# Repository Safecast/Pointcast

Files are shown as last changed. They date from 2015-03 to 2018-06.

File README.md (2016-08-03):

# Pointcast V1.0
New generation nGeigie (work in progress)

Uploads are done through the gateway and go to http://dev.safecast.org

simple software setup:
  - arduino ide 
  - teensyduino or teensy application for uploading hex file into Teensy
  - upgrade firmware instructions are at https://docs.google.com/document/d/16hdhQj_UQkusotejkor8-5BlaK_a2mFPmyVPtsAJ4F8/edit?usp=sharing

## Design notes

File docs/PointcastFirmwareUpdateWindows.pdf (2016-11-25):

2016-11-21 Windows version

Pointcast firmware update (Windows)

1. Download teensy.exe from https://github.com/Safecast/Pointcast/blob/master/app/teensy.zip
2. Extract the file and run the program.
3. Download the Ethernet or 3G zip file as appropriate for your Pointcast device: (https://github.com/Safecast/Pointcast/blob/master/Pointcast_V1_0.V4.2.3_EN.hex.zip and
https://github.com/Safecast/Pointcast/blob/master/Pointcast_V1_0.V4.2.3_3G.hex.zip ).
4. Unzip the Pointcast_V1_0.V4.2.3_EN.hex.zip or the Pointcast_V1_0.V4.2.3_3G.hex.zip to get the HEX file, and place it on your desktop.
5. Run the Teensy.exe
6. Load the hex file from file “open” menu.
7. Switch off the power by:
a. Ethernet Pointcast unplug the ethernet connector.
b. 3G Pointcast disconnect the DC power plug.
8. Remove the clear cover of the Pointcast box by unscrewing the four screws.

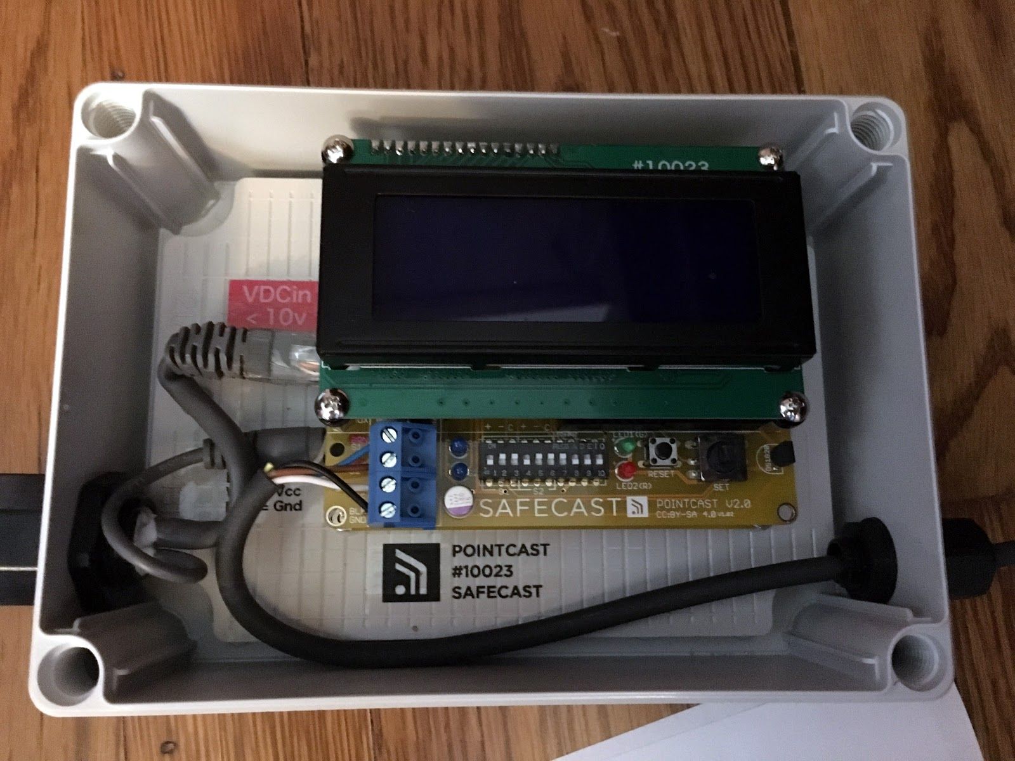
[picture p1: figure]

9. As you can see for the Pointcast V2, there are four layers of boards:
a. The bottom-most gray board with the black Safecast logo and serial number
b. The “Processor Board” that is mounted to it
c. The “Sensor Board” that is plugged into the processor board, and which has the blue screw terminals for the sensor
d. The topmost “Display Board” that is plugged into the Sensor Board.

10. What you want to do is to get access to the Processor Board. Fortunately, you don’t need a screwdriver to do so, because the Sensor Board is merely plugged into a socket on the Processor Board, with nothing more than the tension of the pins and sockets holding it in place.
11. Carefully and gently grab both the left and right sides of the Sensor Board, and wiggle them until the Sensor Board separates from the Processor board, like this:

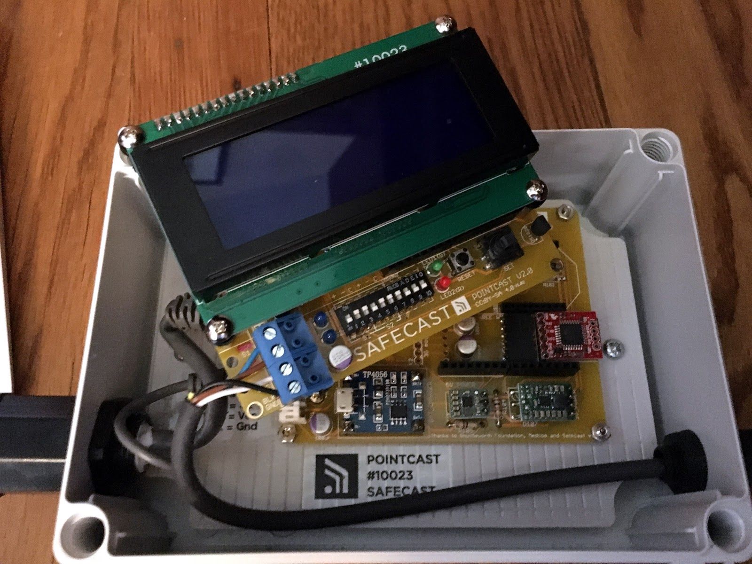
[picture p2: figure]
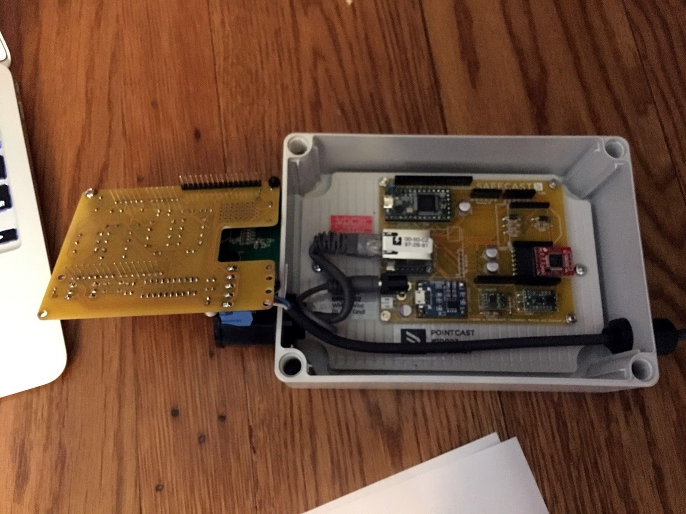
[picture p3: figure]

12. Now, look carefully at the board. You’ll see the Teensy processor card, which has a button on it.

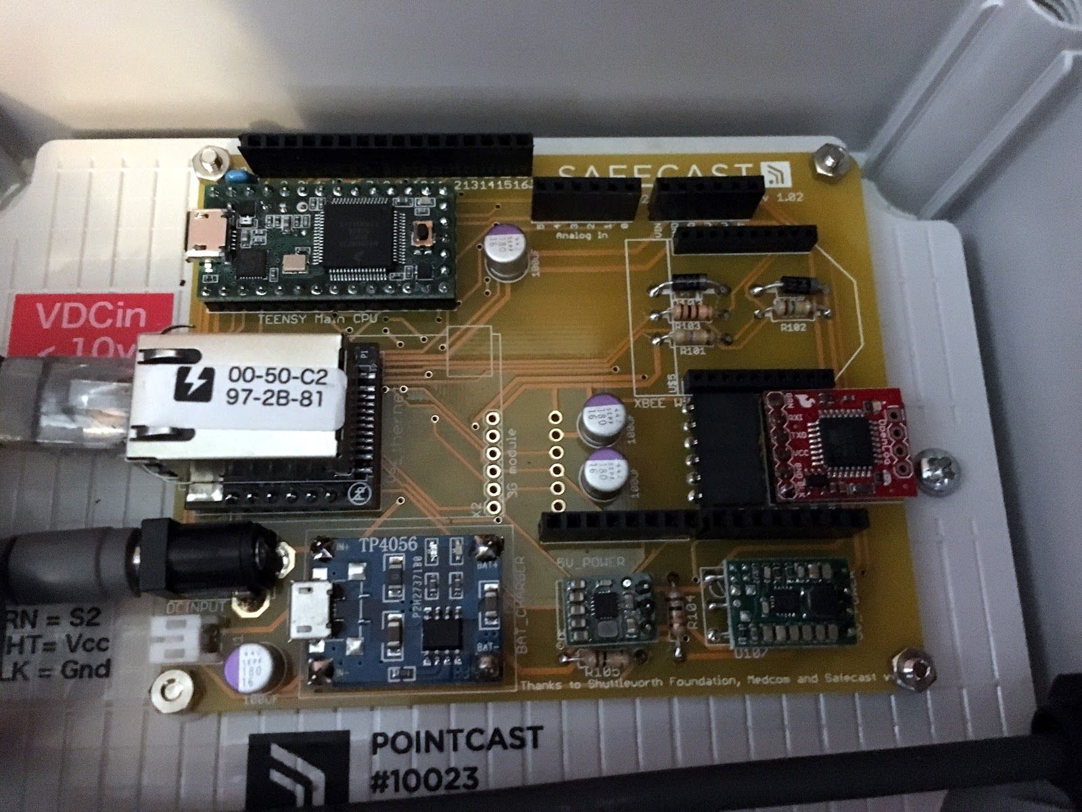
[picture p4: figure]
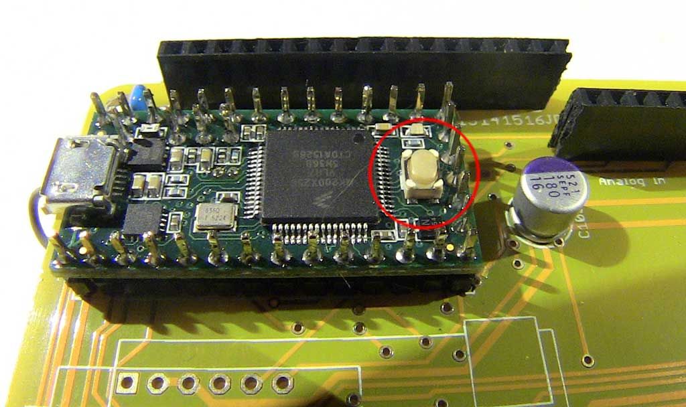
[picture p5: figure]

13. Connect the Teensy on the Processor Board to your computer with the MicroUsb cable.
14. Press the program button of the Teensy.
15. Unplug the Micro USB cable from the Teensy on the Processor Board.
16. Carefully, CAREFULLY plug the Sensor Board back into the Processor Board - looking at an angle at the topmost connector while you’re doing so to ensure that all the pins are aligned and that there aren’t pins sticking outside the socket on one side or another. Gently but firmly make sure the Sensor Board is tightly seated on the Processor Board.
17. Screw the clear plastic cover back onto the Safecast box
18. Plug the ethernet cable back into the box.
19. You’re done. The Pointcast should be booting.

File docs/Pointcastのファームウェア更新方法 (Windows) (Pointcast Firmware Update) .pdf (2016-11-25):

2016-11-21 Windows version

### Pointcastのファームウェア更新方法 （Windows版）

1. Teensy.exe を下記のリンクよりダウンロードします。 https://github.com/Safecast/Pointcast/blob/master/app/teensy.zip
2. ファイルを解凍（展開）し、プログラムを起動させます。
3. Pointcast の機器の仕様に合わせて、Ethernet 又は 3G 用 zip ファイルを下記のリンクよ りダウンロードします。
Pointcast の機器が Ethernet に対応している場合： https://github.com/Safecast/Pointcast/blob/master/Pointcast_V1_0.V4.2.3_EN.hex.zip Pointcast の機器が 3G に対応している場合： https://github.com/Safecast/Pointcast/blob/master/Pointcast_V1_0.V4.2.3_3G.hex.zip
4. 3.の zip ファイルを解凍（展開）して得られた HEX ファイルをデスクトップ上に保存し ます。
5. Teensy.exe を起動します。
6. [File]メニューの[open]より、HEX ファイルを選び、同ファイルを開きます。
7. Pointcast の機器の仕様に合わせて、電源を切ります。
Pointcast の機器が Ethernet に対応している場合：
Pointcast の機器から、Ethernetのプラグを抜きます。
Pointcast の機器が 3G に対応している場合：
Pointcast の機器のDC電源のプラグを抜きます。
8. Pointcast の筐体に付けられている4本のねじを外し、透明色の蓋部を取り外します。


9. Pointcast の機器が、4枚の基板により構成されていることを確認します。

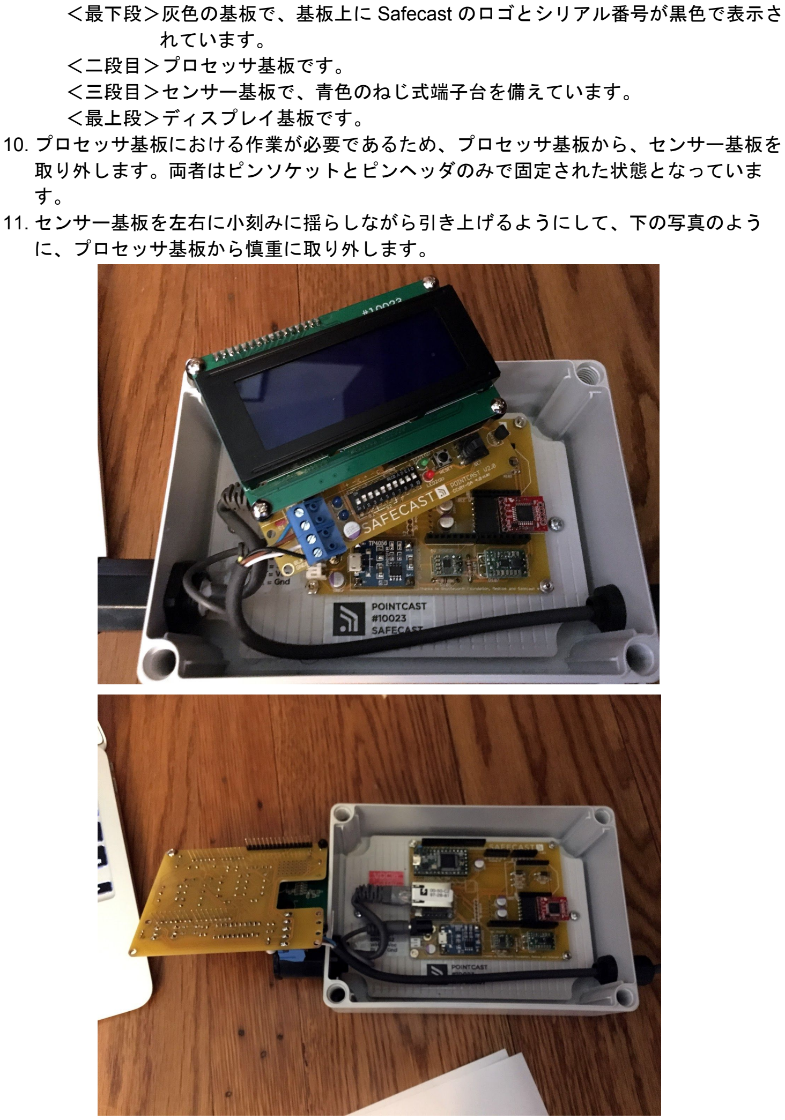
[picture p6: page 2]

＜最下段＞灰色の基板で、基板上に Safecast のロゴとシリアル番号が黒色で表示さ れています。
＜二段目＞プロセッサ基板です。
＜三段目＞センサー基板で、青色のねじ式端子台を備えています。 ＜最上段＞ディスプレイ基板です。
10. プロセッサ基板における作業が必要であるため、プロセッサ基板から、センサー基板を 取り外します。両者はピンソケットとピンヘッダのみで固定された状態となっていま す。
11. センサー基板を左右に小刻みに揺らしながら引き上げるようにして、下の写真のよう に、プロセッサ基板から慎重に取り外します。

12. プロセッサ基板を確認します。プログラムボタン（下の写真の赤色枠中）の付いた Teensy プロセッサ基板が見えます。


13. プロセッサ基板上の Teensy プロセッサ基板とパソコンをマイクロUSBケーブルで接続 します。
14. Teensy プロセッサ基板のプログラムボタンを押します。
15. マイクロUSBケーブルを Teensy プロセッサ基板から外します。
16. センサー基板をプロセッサ基板の上に戻します。＜注意＞全てのピンヘッダがピンソ ケットに収まっていることを確認しながら、慎重に作業を行って下さい。 優しく取り扱 いながらも、センサー基板がプロセッサ基板に固着していることを確認して下さい。
17. Pointcast 筐体の蓋部をねじで取り付けます。Pointcast の機器が 3G に対応している場 合は、これで作業終了となります。
18. Pointcast の機器が Ethernet に対応している場合、 Ethernet ケーブルのプラグを差し込 みます。
19. Pointcast が起動していることを確認して下さい。

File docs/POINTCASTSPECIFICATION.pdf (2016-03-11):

SAFECAST POINTCAST V1.0

Revision:

1.0 April 2015
first draft

1.0.1
incorporated feedback on 1.0 draft

1.0.2
include additional stats under STATS window (1.15)
include parameter for setting the integration window (3.10) (1.6)
add parameter for setting the upload window (e.g. integration window and upload window don’t need to be the same) (3.10) (1.6)
add counter for number of resets, uptime (1.15)
add deadtime correction (3.9)

1.0.3
small changes to 1.1 layout
1.2 screen layout and logic for BAT/EXT power mode detection

1.0.4
move SDCARD screen before TIME screen
NGEIGIE.TXT renamed to PNTCAST.TXT
all screens to 5s
changed SD log format

1.0.5
joystick down on startup, 1 second screen display till “API” screen.
joystick enter(push center button) clears eeprom on startup and clear alarm button on main screen.

1.0.6
Time setup automatically for GMT (later need to be modified for timezones)
SDcard added option for 5 seconds upload for testing/trouble shooting (trb=1)

1.0.7
Handling of MAC
1.08
FAILS handling

1.1 Functions Shield
triple input dual geiger tube input (S1,S2) + one aux input (AUX) float/pull up/pull down 47k for each input line
bypass coupling caps for each input line
LED monitoring of 2 geiger input lines (analog circuit)
Green LED heartbeat
Red LED alarm / error condition
Reset button
Joy stick for screen operation
Digital Temperature sensor
Alarm Buzzer
20x4 LCD interface (dimmable)

1.2 Functions Mother Board
Main controller Teensy
Data Logger (SD card)
System Setup (SD Card)
Power supply USB, External, Battery (3.3 / 5v) Battery charge status (analog input)
Ethernet Interface (optional)
3G Interface (optional)
Xbee Interface for BLE or Wifi (optional)
1.3. SD Card files
PNTCAST.TXT system setup
SENSORS.TXT sensors setup
NETWORK.TXT communication setup
CONFIG.TXT data logger setup (fixed)
XXXXXXXX.LOG historical logs (one file per day)
BUFFER.TXT measurements not uploaded successfully

### 2. SCREEN FLOW

1.1 Startup Screen (5s)

Procedures:
RED/GREEN LED ON (test)
Buzzer ON
Read Device ID from flash memory this is the fixed serial number for the POINTCAST (this can be set from SD card)
INTERUPT: Joy stick enter CLEAR EEPROM settings
INTERUPT: Joy stick DOWN (close screen within 5s timer and other setup screens 1 second display only)

+----+----+----+----+
|SAFECAST POINTCASTv1
|Firmware: X.XX.XX
|DeviceID: XXXX
|http://safecast.org
+----+----+----+----+

1.2 System Status (5s)

Procedures:
read PWR status:
BAT <4.5v
EXT >4.5v
Main power voltage Y.YYV
Bat% (if in BAT mode) based on Nano algo
Pointcast Internal Power Z.ZV
read Tmp sensor (now setup to be send as deviceID+8)

+----+----+----+----+
|SYSTEM
|PWR: EXT/BAT Y.YYV
|Bat: XXX% TNSY: Z.ZV
|Tmp: +XX.XC
+----+----+----+----+

1.3 Read SD Card files (5s)

Procedures:
Read PNTCAST.TXT and set flash memory

Read NETWORK.TXT and set flash memoryRead SENSORS.TXT and set flash memory
If no SD card, then load defaults or use past values set.

⇒ Possible to read name of SDcard and bytes left?
⇒ Show Fail reason?

+----+----+----+----+
|SDCARD FAIL/PASS XXXMB
|PNTCAST: FAIL/PASS
|SENSORS: FAIL/PASS
|NETWORK: FAIL/PASS
+----+----+----+----+

1.4 Time (5s)

Procedures:
Read time from RTC
Read time zone from flash memory (Can be set by PNTCAST.TXT) Adjust time by time zone (setup for UTC)
INTERUPT: Joy stick PUSH (to enter Time Setup screen)
INTERUPT: Joy stick DOWN (close screen within 5s timer)

+----+----+----+----+
|TIME (GMT)
|Date: YYYY/MM/DD
|Time: HH:MM:SS
|Zone: +9
+----+----+----+----+

1.5 Set Time (5s)
does n
This screen should be after network test has been done, so there’s confirmation there’s a network. In case of no network, RTC will be used, with option to use joystick to adjust the RTC. If network is available, attempt will be made to use pool.ntp.org for setting the time. If NTP fails, use RTC, with option to change it (so wait additional 5 seconds for setup)

Time should be set in GMT. Display to show local time.

If RTC is not set manually or by NTP, timestamp to be flagged “invalid”. Some thinking needed how to use RTC when on battery. So check what RTC is when cold boot happens if detected it’s “not set”, flag as invalid, till RTC or manually set has been performed.

Procedures:
Read time from RTC
Read time zone from flash memory (Can be set by PNTCAST.TXT) Adjust time by time zone
INTERUPT: Joy stick:
Up/Down increase/decrease field
Left/Right move prev/next field
Center Set and Close screen

Display on screen if NTP server connected or not

+----+----+----+----+
|RTC check...
|please wait a couple
|seconds...
+----+----+----+----+

succeed:
+----+----+----+----+
|NTP server:
|45.79.78.173
|time:
+----+----+----+----+

fail
+----+----+----+----+
+----+----+----+----+

1.6 POINTCAST parameters (5s)

Procedures:
read parameters from flash
INTERUPT: Joy stick DOWN (close screen within 5s timer)

+----+----+----+----+
|POINTCAST SETUP
|DeviceID: XXXX
|TimeZone: -9
|ALARM-S1: 150 CPM
+----+----+----+----+

+----+----+----+----+
|UPLOAD MODE
|Adaptive: OFF
|Integr Win: 300sec
|Upload Win: 300sec
+----+----+----+----+

1.7 GPS location (5s)

Procedures:
read parameters from flash
INTERUPT: Joy stick DOWN (close screen within 5s timer)

⇒ Option offer function to edit location or read from GPS module

+----+----+----+----+
|GPS LOCATION
|Lon: 12.3456
|Lan: 12.3456
|Alt: 100m
+----+----+----+----+

1.8 SENSORS parameters (3s)

Procedures:
read parameters from flash
INTERRUPT: Joy stick DOWN (close screen within 5s timer) Leave Aux for now, just show NC
INTERUPT: Joy stick DOWN (close screen within 5s timer)

+----+----+----+----+
|SENSORS SINGLE/DUAL
|S1=334 CPM/uSv Cs137

|S2=120 CPM/uSv Cs137
|AUX=NC
+----+----+----+----+

1.9 SENSORS test/auto detect sensors (max 60 sec)

Procedures:
read pulse from S1 if no pulse in 30sec, then FAIL. PASS on first pulse read pulse from S2 if no pulse in 30sec, then FAIL. PASS on first pulse
based on result, update sensor config
INTERRUPT: Joy stick DOWN (close screen within 5s timer)

⇒ Theoretically time out can be set based on the CPM for each sensor bit academic

+----+----+----+----+
|SENSOR TEST
|S1=PASS/FAIL
|S2=PASS/FAIL
|AUX=NC
+----+----+----+----+

1.9 API parameters (5s)

Procedures:
read parameters from flash
INTERRUPT: Joy stick DOWN (close screen within 5s timer) Leave Aux for now
Display full API key (20 chars, no need for “API-KEY” label)

+----+----+----+----+
|API
|S1-ID=XXXX
|S2-ID=YYYY
|sdffkDSFsdkj
+----+----+----+----+

1.10 NETWORK configuration (5s)

Procedures:
read parameters from flash (read which network interface is selected) read NIC/IP/GW from Ethernet or Wifi
read other stuff from 3G like signal strength, carrier, phone number, etc

read NIC from BLE
INTERRUPT: Joy stick DOWN (close screen within 5s timer)
Show top line first, before starting network status check. If time out, show: No LAN detected and wait for 5s

+----+----+----+----+
|NETWORK ETHER (DHCP)
|IP: AAA.BBB.CCC.DDD
|GW: AAA.BBB.CCC.DDD
|ID NN:NN:NN:NN:NN:NN
+----+----+----+----+

+----+----+----+----+
|NETWORK WIFI (DHCP)
|IP: AAA.BBB.CCC.DDD
|GW: AAA.BBB.CCC.DDD
|ID NN:NN:NN:NN:NN:NN
+----+----+----+----+

+----+----+----+----+
|NETWORK 3G
|Signal: |ooooo|
|Carrier: NTT Docomo
|GW: AAA.BBB.CCC.DDD
+----+----+----+----+

+----+----+----+----+
|NETWORK BLE
+----+----+----+----+

ID MAC-Address
if not available from the interface API, show value read from EEPROM
in SD card, parameter for MAC is “macid” that will be stored in EEPROM upon reading the SDcard.

1.11 NETWORK test (5s)

Procedures:

initialize Network Interface (Ethernet/3G/BLE/WIFI)
connect to api.safecast.org/gateways check if Internet is available and if Safecast GW is reachable.. V3.6.7 checks http://api.safecast.org for redirect to https and returns a
301. If successful flags the connection as valid.
if fail, try twice if not, reset and startup with random GW
RED LED if fail. on next time of PASS RED LED will be reset
INTERRUPT: Joy switch DOWN (close screen within 5s timer)
Joy switch to right will ping the api and will pause the progress. Next screen will happen on joy switch down.

⇒ For Ether, 3G, Wifi, BLE sleep interface after test

+----+----+----+----+
|NETWORK TEST (ETHER/3G/BLE/WIFI) |Device: PASS/FAIL
|GW: AAA.BBB.CCC.DDD
|Ping : PASS/FAIL
+----+----+----+----+

1.12 YYYYMMDD.LOG creation (5s)

Procedures:
Create or append to Log file
Read NETWORK.TXT and set flash memory
Read SENSORS.TXT and set flash memory
If no SD card, then load defaults or use past values set.

⇒ Possible to read name of SDcard and bytes left?
⇒ Show Fail reason? In terminal screen

+----+----+----+----+
|DATA LOGGER
|YYYYMMDD.LOG: NEW/FAIL
|XXXX MB Free
+----+----+----+----+

1.13 Main Loop Screen

Procedures:
RED LED ON IF Upload Fail OR CPM-S1=0 OR CPM-S2=0 OR ALARM = TRUE RED LED ON if S1 >> S2 in uSv/h (or other way around factor 3)
GREEN LED ON if RED LED = FALSE (if possible, shortly blink every 10 sec)

If upload fails, show FAIL(n) where n is number of measurements in buffer
FAILS show how many retries left in 3G
FAILS on Ethernet show which sensor send data is failing STS show remaining seconds to next upload and Antenna Strength. In case on Battery, show battery left%. Refresh every 10 seconds.
STS use for any additional detail in case of a RED LED (e.g. “ALPHA/BETA!”, “SPIKE!”, “S1 FAIL”, “BAT LOW”)
LOG show time in local time zone (no summer time adjust!)
INTERRUPT Joystick UP button scroll through all Setup pages
INTERRUPT Joystick DOWN button scroll through Stat pages
INTERRUPT Joystick LEFT button show terminal screen 1.14
INTERRUPT Joystick RIGHT button show Antenna Strength screen (refresh every 1s for quick response)
INTERRUPT RESET button hard reset system

+----+----+----+----+
|S1=9999 CPM m.mm uSh
|S2=10.1kCPM mmmm uSh
|API: HH:MM PASS/FAIL(nnn) |STS: OK 4:50 |ooooo|
+----+----+----+----+

For the first sample, show following status (and show measurements as 0)

|API: HH:MM Startup..

1.14 Terminal screen

+----+----+----+----+
|TERMINAL
|res=z1
|res2=
+----+----+----+----+

Simple screen to live show the output to LPR for in the field trouble shooting. (kind of verbose mode)

1.15 Stat screens

Procedures:
Scroll through automatically, each screen 10s, then return to 1.13 INTERRUPT Joystick DOWN button stat 2
INTERRUPT Joystick UP button goto return to 1.13
Stat-1

+----+----+----+----+
|STATS
|S1peak=9999 CPM
|S2peak=9999 CPM
|Dose=9999999 uSv
+----+----+----+----+

Stat-2:
Procedures:
INTERRUPT Joystick UP button goto Stat-1 page INTERRUPT Joystick Down button return to 1.13

+----+----+----+----+
|up=xxx days hh hour
|#logs=nnnn
|#fail=ffff
|#reset=rrrr
+----+----+----+----+

### 3. DESIGN NOTES

3.1 Adaptive Logging
when radiation levels change by x %, log radiation every y seconds instead of t seconds

3.2 Periodic reset DONE
based on rst parameter, hard reset Pointcast every x
resets every saturday

3.3 Battery low power mode
shutdown display and network subsystems log to BUFFER.TXT file instead

3.4 SD CARD management DONE
create new file for each day YYYYDDMM.TXT
how to handle full SD card TBD ⇒ Reality is to fill 4GB card it will take 10’s of years.

3.5 Log buffer (buffer.txt)
when upload fails, append failed measurements to BUFFER.TXT, increase BUF counter retry if succeeds, upload all from BUF. Set BUF counter to zero when complete. If fails, continue with next measurement

3.6 Dev mode (network.txt) DONE
dev parameter flips between dev and prod servers (retaining all other parameters for seamless promotion of a sensor after test to deployment.

3.7 Set RTC from NTP server (option) DONE

3.8 Wifi
build around Wifi bee module setting of network to be done over Wifi and no need for parameters to setup the module at this point

3.9 Deadtime correction
apply deadtime correction to CPM values before upload
formula:
c_p_m = (unsigned long)((float)c_p_m/(1-(((float)c_p_m*1.8833e-6))));

3.10 Integration and Upload window
integration window (in seconds)
upload window (in seconds)
capability to set the integration window based on the sensor sensitivity
capability to upload data on the same or slower pace as the integration window
these mode may be overwritten by the adaptive upload method, where updates are based on change rather than interval (3.1)

### 4. GATEWAY/API

See:

https://docs.google.com/document/d/1ZxJI0ODhpgQ0rvSRrRyq1NAwyiliyxd7bJkL8JX76e8/edit (https://docs.google.com/document/d/1ZxJI0ODhpgQ0rvSRrRyq1NAwyiliyxd7bJkL8JX76e8/edit)

### 5. SD CARD FILE FORMATS

5.1 PNTCAST.TXT

devid=XXXX | #unique Pointcast DeviceID
lat=34.482597 | #latitude
lon=136.163349 #longitude
alt=100 | #altitude in meters
tws=300 | #integration window in seconds
ups=300 | #upload window in seconds tws <= ups
autow=1 | #auto adaptive window for sudden changes
rst=0 | #periodic reset in days (0 is OFF)
alm=150 | #alarm for S1 sensor in CPM
tz=+9 | #timezone adjust (0 is GMT)
trb=0 | #switch to 5 seconds update mode for troubleshooting

5.2 NETWORK.TXT

intf=EN/3G/BT/WF #interface selection: EtherNet 3G BlueTooth WiFi macid=xx.xx.xx.xx.xx.xx # MAC-Address for Ethernet cards.
uid1=nnnn | # API ID for upload of data from S1 sensor
uid2=nnnn | # API ID for upload of data from S2 sensor
devt1=nnnn | # API device type sensor 1 LND7317 (129) LND712(130)
devt2=nnnn | # API device type sensor 2 LND7317 (129) LND712(130)
api=AzQLKPwQqkyCTDGZHSdy #20 char api key | # API for Pointcast
gw01=107.161.164.166 | # Gateway 01
gw02=107.161.164.163 | # Gateway 02
ssid=mywifi | # WiFI SSID
apn=DMM | # apn for 3G name
pwd=******** | # pwd for Wifi
gwnn= | # Gateway nn
dev=0 | #flip between prod and dev servers

5.3 SENSORS.TXT

s1e=1 | #Sensor 1 enabled
s1f=334 | #Sensor 1 uSv/h conversion factor
s1i=Cs137 | #Sensor 1 Isotope
s2e=1 | #Sensor 2 enabled
s2f=120 | #Sensor 2 uSv/h conversion factor
s2i=Cs137 | #Sensor 2 Isotope
aux=0 | #Aux input (not in use)

5.4 YYYYMMDD.TXT

$PNTDD,95,2015-04-08T03:22:00Z,,,0,A,3428.9558,N,1369.8009,E,1,A,,*5C $PNTXS, 1001,23,4.89,*4D (device id, temperature, voltage, etc)

5.5 BUFFER.TXT

$PNTDD,95,2015-04-08T03:22:00Z,,,0,A,3428.9558,N,1369.8009,E,1,A,,*5C $PNTXS, 1001,23,4.89,*4D

5.6 CONFIG.TXT

9600,26,3,2

### 6. FLOW DIAGRAM

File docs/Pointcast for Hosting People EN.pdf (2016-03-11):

160227

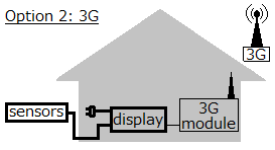
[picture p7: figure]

1

Thank you for your interest in and support of Safecast, and for participating in the Pointcast project.

Pointcast Project and Instrument:

The Pointcast project is intended to visualize changes in radiation levels over time at fixed locations all over the world, by installing real time radiation monitoring systems.

The Pointcast instrument can detect alpha, beta and gamma radiation. It uses a communication module (external dimensions: 120x175x60mm) either indoors or outdoors, and an outdoor dual-sensor module (external dimensions: 80x160x65mm), connected to each other by a cable. The instrument will operate with an AC adapter (5-7.5VDC 2A). The system is connected to the Internet, and the measurement data will be displayed on our webpage. (http://realtime.safecast.org)
Photo
Communication module
Dual Sensors module
The Pointcast instrument will be installed by Safecast volunteers.

Joining and Cooperating with the Pointcast project:

Installing the Pointcast instrument requires you to supply power, and internet access through a LAN cable. If internet access is not available at your location, Safecast can supply a 3G wireless module.

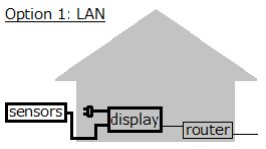
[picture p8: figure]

If any errors occur on the Pointcast instrument, the communication module will alert you with a red LED and beep three times.

What the Pointcast Instrument Shows You：

On the display of the Pointcast communication module, you will be able to see the real time radiation levels detected from both sensors, in CPM and μSv/h. Sensor 1 (displayed as S1) is a pancake-style Geiger-Müeller tube designed to detect alpha, beta and gamma radiation. Sensor 2 (displayed as S2) is

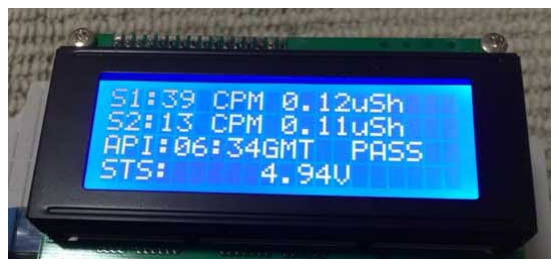
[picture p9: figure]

an end window type Geiger-Müeller tube configured for detecting gamma radiation.

160227

2

Normally, the both sensors will show approximately the same radiation levels (±25%). If the gamma radiation level in the air is high, both will indicate the level of gamma radiation (since both sensors detect gamma radiation). However, if there are nuclides in the air that emit beta or alpha radiation, besides gamma, the pancake style sensor (S1) will likely read higher. In that case, please refer to the CPM reading, not the dose rate (µS/h), because it will not be applicable for S1. Regarding Sensor 2 (S2), readings of both CPM and the dose rate are applicable.

Following “API:,” the last time at which the data was sent to our server is displayed in Greenwich Mean Time (GMT), and “PASS” means that the data was uploaded to our server successfully. For Japan time, please add nine hours.

On the last line of the display, when nothing is displayed after “STS:,” it means that the communication module is working properly. The voltage indication on the right side is the input voltage to the communication module circuit from power supply. It should be between 3.5 and 7.5 V.

On the case of the Pointcast communication module, two URLs are given for locating the real time data from each sensor online.

Precautions after Installing the Pointcast Instrument:

- Keep the Pointcast instrument away from vibration, high humidity, heat, and direct sunlight as much as possible.
- Please do not let the Pointcast instrument directly touch radioactive materials, in order to prevent contamination from distorting the readings.
- Please do not scratch or damage the mica window of the Pointcast sensor module.
- Unless requested to do so by our volunteers, please do not open, uninstall, disassemble, repair, or modify the Pointcast instrument.

If You Find Any Failure of the Pointcast Instrument:

We will request you to provide your contact information to us. A volunteer will probably contact you regarding the condition of the Pointcast instrument. In such a case, a timely response will help resolve the problem quickly. If you have a preferable day and time to be contacted, please let us know.

Our volunteers will ask you to describe the problem. Depending on the problem, we may ask you to assist in fixing the failure. In this case, your help would be appreciated.

Contact Safecast Pointcast Project:
Pieter Franken (Tel: 080-3351-4519 E-mail: pieter@safecast.org) Rob Oudendijk (Tel: 080-2260-5966 E-mail: rob@safecast.org) Kiki Tanaka (Tel: 090-9800-3337 E-mail: kiki@safecast.org)

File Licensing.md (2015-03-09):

Licensing Read Me

Licensing can be confusing. We’ll try to make it a little less so.

Design, hardware, software, design and website content is shared by Safecast under the licenses specified below. 

When you contribute to Safecast by [participating in this event] OR [submitting content of information to the webpage] OR [(Github) submitting a pull request, testing or bug reporting] OR [sending data from your Safecast device] then you license all of your contribution to Safecast and to all the world under these same licenses. Safecast will be attributed as the source.

	•	All Data is Creative Commons Zero (http://creativecommons.org/publicdomain/zero/1.0/), anyone is free to make any use of the data, attribution is not legally required but is encouraged;
	•	All Design is Creative Commons Attribution Share-Alike (http://creativecommons.org/licenses/by-sa/4.0/), anyone is free to copy, edit and republish the design but must make it clear Safecast is the source and the design must be published under the same or a compatible license;
	•	All ufnctional aspects of design are under the Berkeley Software Distribution License (https://blog.safecast.org/bsd) in respect of copyright and the XL1.0 Cross Licence 
	•	(http://blog.safecast.org/wp-content/uploads/2012/05/xl_crosslicense.pdf) in respect of patent;
	•	Web Content is under Creative Commons Attribution Non Commercial (http://creativecommons.org/licenses/by-nc/3.0/), anyone can copy and remix the what is on the website but must attribute Safecast and anyone else specified by  Safecast.

“Safecast” and the safecast logo are Registered Trademarks of the Momoko Ito Foundation, a 501(c)3 Non-profit, you can't use them without permission. For permission email

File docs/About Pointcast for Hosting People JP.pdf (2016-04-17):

セーフキャストの活動にご賛同いただき、Pointcast（ポイントキャスト）プロジェ クトにご参加・ご協力いただき有難うございます。

ポイントキャスト・プロジェクトと機器について:

ポイントキャスト・プロジェクトは、リアルタイム放射線量モニタリング・システ ムを世界各地に設置することにより、一定の場所における経時的な放射線量の変化 を可視化することを目的としています。

ポイントキャスト機器は、通信器（外寸: 120 x 175 x 60 mm）を屋内または屋外に設 置し、デュアルセンサー・モジュール（外寸: 80 x 160 x 65 mm）を屋外に設置し、両 者をケーブルで接続することにより、アルファ、ベータ、ガンマ線を検出すること が可能です。同機器は、AC アダプター（5V、2A）で作動します。データはインター ネットを介して当団体ウェブサイトに表示されます。（http://realtime.safecast.org）

通信器：

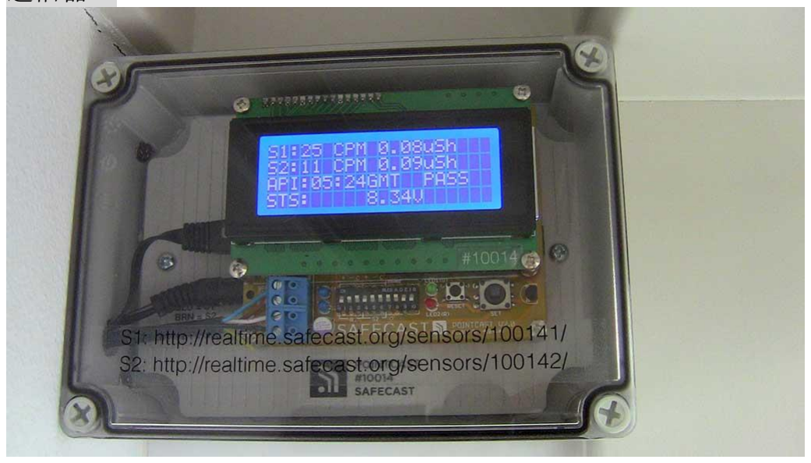
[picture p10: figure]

デュアルセンサー・モジュール：

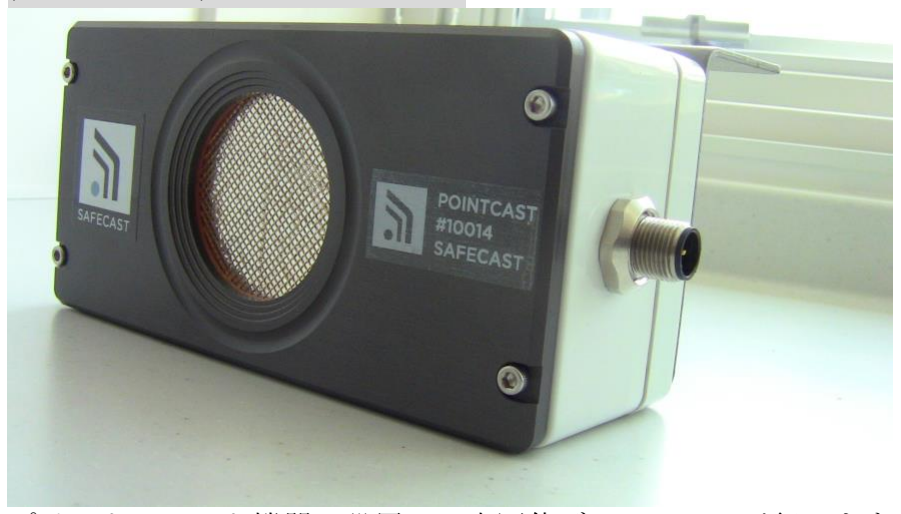
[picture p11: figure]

ポイントキャスト機器の設置は、当団体ボランティアが行います。

ポイントキャスト・プロジェクトへのご参加・ご協力について:

ポイントキャスト機器を設置するに当たり、電源と LAN ケーブルによるインターネ ットへの接続環境をご提供いただきます。ご自宅にインターネット環境がない場合、 当団体が 3G 通信機器をご用意します。

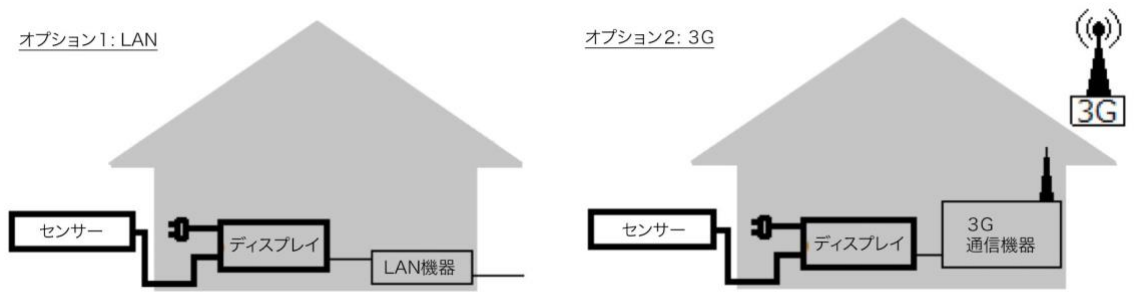
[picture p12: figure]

万が一、機器に不具合が生じた場合、通信モジュール部の赤色 LED 警告灯とビープ 音（3 回）により、異常をお知らせします。

ポイントキャスト機器から判ること:

通信器のディスプレイには、２台のセンサーから検出さ
れた放射線量がリアルタイムで CPM と μSv/h の単位に て表示されます。センサー１（ディスプレイ上では S1） は、パンケーキ型ガイガー＝ミュラー計数管を利用し、
アルファ、ベータ、ガンマ線を検出するように設計され

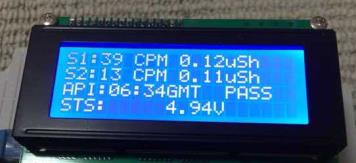
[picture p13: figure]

ています。センサー２（ディスプレイ上では S2）は、端窓型ガイガー＝ミュラー計 数管を利用し、ガンマ線を検出するように設計されています。大抵の場合、両セン サーは、ほとんど同じ放射線量を表します（±25%）。大気中にガンマ線量が高い 場合、両センサーともガンマ線を検出するため、両センサーはガンマ線量の値を示 します。大気中の核種がガンマ線以外にベータ線やアルファ線を放出する場合は、 センサー１の方が高い値を示します。この場合、センサー１に関しては、線量率 (µS/h)の測定値は不適切な値であるため、CPM 値のみをご参考下さい。センサー２に 関しては、線量率(µS/h)値と CPM 値ともにご参考いただけます。

ディスプレイ上の「API:」の項目は、API にデータを送信した最終時刻をグリニッジ 平均時（GMT）で表します。「PASS」の表示は、データがサーバーにアップロード されたことを示します。日本時間への変換は、GMT より 9 時間進めて下さい。

ディスプレイ上の最下行の「STS:」の項目に何も表示がない場合は、通信器が正常に 作動していることを示します。右側に表示される電圧の値は、電源から通信器へ入 力される電圧（通常 3.5〜7.5V）の値を示します。

通信器の上蓋に示す URL は、センサー１（S1） とセンサー２（S2）それぞれのリア ルタイムデータが表示されるウェブサイトのアドレスです。

ポイントキャスト機器を設置後にご注意いただきたい事項:

- 機器が、振動、高温、多湿、直射日光をできる限り避けることができるようご配 慮ください。
- 機器の汚染を避けるため、同機器が放射性物質に触れないようにしてください。
- デュアルセンサー・モジュールの雲母窓を引っかく等、傷をつけないでください。
- 当団体ボランティアから依頼しない限り、機器を開けたり、取り外したり、その 他、解体、修理、改造しないでください。

ポイントキャスト機器に故障や不具合が発生した場合:
ポイントキャスト機器に故障や不具合を発見されましたらプロジェクト窓口に至急 ご連絡ください。当団体ボランティアが同機器の状態についてお尋ねします。機器 の状態により対処方法は異なりますが、ご協力をお願いする場合があります。その 際は、ご対応をいただきたく、よろしくお願い致します。

また、当団体ボランティアからも、機器の状態に関して、ご連絡をすることがある ため、同プロジェクトにご参加いただく皆様には、連絡先情報を当団体にご登録い ただいております。当団体からのご連絡には、必ずご応答いただきたく、よろしく お願い致します。当団体からご連絡をする場合にご希望の時間帯・曜日等ございま したら、予めお知らせください。

セーフキャスト・ポイントキャスト・プロジェクト窓口: ピーテル・フランケン（Tel: 080-3351-4519 E-mail: pieter@safecast.org） ロブ・アウデンダイク（Tel: 080-2260-5966 E-mail: rob@safecast.org） 田中 響子（Tel: 090-9800-3337 E-mail: kiki@safecast.org）

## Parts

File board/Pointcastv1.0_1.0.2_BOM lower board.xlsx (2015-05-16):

Part | Value | Device | Package | Description | PROD_ID
3V_POWER |  | POLOLU_D24V3AXV | POLOLU_D24VXAYV_HC | Pololu Adjustable Step Down Voltage Regulators Series D24V3A_V (300 mA)0.4x0.6""
5V_POWER |  | POLOLU_S7V8F5 | POLOLU_S7V8F5 | POLOLU_S7V8F5
BAT_CHARGER | TP4056_CHARGER | TP4056_CHARGER | TP4056 | TP4056
C2 | 0.1uF | C-EU025-024X044 | C025-024X044 | CAPACITOR, European symbol
C101 | 100uF | CAP_POLPTH1 | CPOL-RADIAL-100UF-25V | Capacitor Polarized
C102 | 100uF | CAP_POLPTH1 | CPOL-RADIAL-100UF-25V | Capacitor Polarized
C103 | 100uF | CAP_POLPTH1 | CPOL-RADIAL-100UF-25V | Capacitor Polarized
C104 | 100uF | CAP_POLPTH1 | CPOL-RADIAL-100UF-25V | Capacitor Polarized
CN1 |  | JST_2PIN-THM-RA | JST-PH-2-THM-RA | JST 2-Pin Connectors of various flavors
D101 | 1N4004 | 1N4004 | DO41-10 | DIODE
D103 | 1N4004 | 1N4004 | DO41-10 | DIODE
D105 | 1N4004 | 1N4004 | DO41-10 | DIODE
D107 | 1N4004 | 1N4004 | DO41-10 | DIODE
D108 | 1N4004 | 1N4004 | DO41-10 | DIODE
DATALOGGER | OPENLOG | OPENLOG | OPENLOG | Openlog
DCINPUT | 5Volt | DC21MMX | DC-21MM
FRAME1 | FRAME-LEDGER | FRAME-LEDGER | CREATIVE_COMMONS | Schematic Frame
JP3 |  | M16PTH | 1X16 | 1x16 .1 header"
R101 | 470k | R-US_0207/10 | 0207/10 | RESISTOR, American symbol
R102 | 150k | R-US_0207/10 | 0207/10 | RESISTOR, American symbol
R103 | 100 | R-US_0207/10 | 0207/10 | RESISTOR, American symbol
R104 | 10K | R-US_0207/10 | 0207/10 | RESISTOR, American symbol
R105 | 100k | R-US_0207/10 | 0207/10 | RESISTOR, American symbol
TEENSY | TEENSY Main CPU | TEENSY_3.0_ALLPINS | TEENSY_3.0_ALLPINS | Teensy 3.0 with all pin holes and optional SMD-mount unshrouded header on bottom of Teensy 3.0. For more basic versions, see 'Basic', '+4' and 'AllAnalogPins'.Requires the installation of a un-shrouded SMD header on the underside of the Teensy 3.0
U$5 | XBEE WiFi/BLE | XBEE-2B2 | XBEE-SILK | Xbee module footprints
U6 | Ethernet | WIZ820IO_DEVICE'DUAL-IN-LINE' | WIZ820IO | WIZnet, WIZ820io plug in module incl. W5200 chip and MagJack
X2 | 3G module | M06SILK_FEMALE_PTH | 1X06 | Header 6 | CONN-08437
X4 | 3GS shield | ARDUINO_SHIELDLABEL | DUEMILANOVE_SHIELD | Arduino shield footprint

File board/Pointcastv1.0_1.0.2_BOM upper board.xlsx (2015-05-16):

Part | Value | Device | Package | Description | MF | OC_ADAFRUIT | OC_MOUSER | OC_NEWARK
C1 | 0.1uF | C-EU025-024X044 | C025-024X044 | CAPACITOR, European symbol
C2 | 0.1uF | C-EU025-024X044 | C025-024X044 | CAPACITOR, European symbol
C3 | 0.1uF | C-EU025-024X044 | C025-024X044 | CAPACITOR, European symbol
C4 | 100uf | CAP_POLPTH1 | CPOL-RADIAL-100UF-25V | Capacitor Polarized
C5 | 0.1uF | C-EU025-024X044 | C025-024X044 | CAPACITOR, European symbol
D1 |  | DIODEDIODE_BIG | DO41-10 | Diode
D2 |  | DIODEDIODE_BIG | DO41-10 | Diode
FRAME1 | FRAME-LEDGER | FRAME-LEDGER | CREATIVE_COMMONS | Schematic Frame
J1 | OSTTH050160 | OSTTH050160 | EDSTL130-05 | 5mm Terminal Header
JP3 | Extended header | M16PTH | 1X16 | 1x16 .1 header"
LED1 | (G) | LED3MM | LED3MM | LED
LED2 | (R) | LED3MM | LED3MM | LED
PAD1 | AUX | 2,15/1,0 | 2,15/1,0 | THROUGH-HOLE PAD
PAD2 | 5V | 2,15/1,0 | 2,15/1,0 | THROUGH-HOLE PAD
PAD3 | GND | 2,15/1,0 | 2,15/1,0 | THROUGH-HOLE PAD
PAD4 | 3.3V | 2,15/1,0 | 2,15/1,0 | THROUGH-HOLE PAD
R1 | 47k | R-US_0207/10 | 0207/10 | RESISTOR, American symbol
R2 | 47k | R-US_0207/10 | 0207/10 | RESISTOR, American symbol
R3 | 470 | R-US_0207/10 | 0207/10 | RESISTOR, American symbol
R4 | 470 | R-US_0207/10 | 0207/10 | RESISTOR, American symbol
R5 | 10k | R-US_0207/10 | 0207/10 | RESISTOR, American symbol
R6 | 10k | R-US_0207/10 | 0207/10 | RESISTOR, American symbol
R7 | 4.7k | R-US_0207/10 | 0207/10 | RESISTOR, American symbol
R8 | 1k | R-US_0207/10 | 0207/10 | RESISTOR, American symbol
R9 | 100k | R-US_0207/10 | 0207/10 | RESISTOR, American symbol
R11 | 1k | R-US_0207/10 | 0207/10 | RESISTOR, American symbol
R12 | 100 | R-US_0207/10 | 0207/10 | RESISTOR, American symbol
R13 | 47k | R-US_0207/10 | 0207/10 | RESISTOR, American symbol
R14 | 47k | R-US_0207/10 | 0207/10 | RESISTOR, American symbol
R15 | 10k | R-US_0207/10 | 0207/10 | RESISTOR, American symbol
R16 | 4.7k | R-US_0207/10 | 0207/10 | RESISTOR, American symbol
R17 | 4.7k | R-US_0207/10 | 0207/10 | RESISTOR, American symbol
R18 | 100k | R-US_0207/10 | 0207/10 | RESISTOR, American symbol
R19 | 100 | R-US_0207/10 | 0207/10 | RESISTOR, American symbol
RESET | RESET | DTS-6 | DTS-6
S1 |  | LED3MM | LED3MM | LED
S2 |  | LED3MM | LED3MM | LED
SET |  | SKQUCAA010 | SKQU | Multi Control Devices TACT Switch - 4-directional with Center Push Type. | ALPS | 504 | 688-SKQUCA | 59M1983
SG1 | BUZZER | BUZZERPTH | BUZZER-12MM | Buzzer 12mm
SW1 |  | SW_DIP-10 | EDG-10 | DIP SWITCH
T1 | 2SC1815 | 2SC1815 | TO92-ECB | NPN EPITAXIAL TRANSISTOR
T2 | 2SC1815 | 2SC1815 | TO92-ECB | NPN EPITAXIAL TRANSISTOR
TEMP | AVA_DS1820TO92 | AVA_DS1820TO92 | AVA_DS1820 | DS18B20
X1 | LCD-HD447804-HOLES20X4-4HOLES | LCD-HD447804-HOLES20X4-4HOLES | LCD-20X4-4HOLES
X3 | 3GS shield | ARDUINO_SHIELDLABEL | DUEMILANOVE_SHIELD | Arduino shield footprint

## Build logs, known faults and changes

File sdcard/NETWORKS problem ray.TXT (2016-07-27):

uid1=100231
uid2=100232
devt1=129
devt2=130
intf=EN
macid=90:A2:DA:0E:E0:5E
gw2=107.161.164.166
gw1=107.161.164.163
ssid=mywifi
pwd=12345678
gwn=test
dev=1
apn=SORA

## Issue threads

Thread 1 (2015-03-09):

Software requests/ideas/bug etc..

robouden, 2015-03-09:

robouden, 2015-03-09:
To be implemented :
- Multiple gateway list randomly selected.  Read from SDcard.
- Setup on SDcard for switching Ethernet or 3G.
- Display messages and layout of screen.

robouden, 2015-11-16:
Other things to be worked on:
- timezones setup
- eprom clear from menu
- dead compensation
- failures on SDcard and falling codes
- alarm set
- switch Ethernet-3G on SDcard

Closed 2016-07-08.

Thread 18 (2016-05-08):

9 volt test

robouden, 2016-05-08:
Test for 9 volt adaptor

robouden, 2016-05-08:
Reset for 9 Volt adaptor does not seem to work

robouden, 2016-05-15:
Reset tested works  on Ethernet and does work correctly.

Closed 2016-05-15.

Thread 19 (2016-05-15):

Xbee tests

robouden, 2016-05-15:

nokton, 2016-05-15:
Rob, please see if the pins that the XBee uses are wired on the motherboard correctly or not before testing

 Pieter

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

robouden, 2016-05-15:
will do

robouden, 2016-05-15:
Xbee connected to pin 24/25 on teensy. Software serial test for sending same data from serial 0 (Openlog) to serial 2 (Xbee). Works now

Closed 2016-05-15.

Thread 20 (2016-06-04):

hardware reset

robouden, 2016-06-04:
Hardware pin reset connected to button and i/o pin. So hardware reset will be possible from software

Closed 2016-06-26.

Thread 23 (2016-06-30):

Software reset does not reset 3G module or Ethernet board.

robouden, 2016-06-30:

Closed 2016-07-08.

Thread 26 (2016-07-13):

Random time for restarts

robouden, 2016-07-13:
Weekly restarts needs to be random for preventing all the sensors send data at the same time.

nokton, 2016-07-13:
Make it a function of time elapsed till start + a random seed, not based on RTC

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

robouden, 2016-07-13:
Time elapsed till start  or time elapsed from start ?  I was thinking RTC with random seed so we know roughly restarts times. Maybe within and hour.

nokton, 2016-07-13:
From start

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

thinrope, 2016-07-14:
Each boot, write down (flash) millis()+1week, then periodically (hourly?) check the value and compare to current, reboot if needed. If reboot happens in less than one week - fine; otherwise the device will work at most one week (unless it gets stuck); make sure shorter (1h?) watchdog is set.

Closed 2016-07-21.

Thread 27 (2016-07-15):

First measurement to high

robouden, 2016-07-15:
After power up first measurement is to high.

robouden, 2016-07-17:
V3.9.7 fixed issue

Closed 2016-07-17.

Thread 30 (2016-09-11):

realtime website show "misses" in sending data

robouden, 2016-09-11:
A table and graph for displaying missed data of sensor at RT website.

robouden, 2016-09-11:
test is at https://docs.google.com/spreadsheets/d/1M-cGRrwzN5xHKK9vO_FhC3u_J3ECEa8LG8dkTrSwHu4/edit?usp=sharing

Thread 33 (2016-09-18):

replace println() with println("")

robouden, 2016-09-18:

Closed 2016-09-18.

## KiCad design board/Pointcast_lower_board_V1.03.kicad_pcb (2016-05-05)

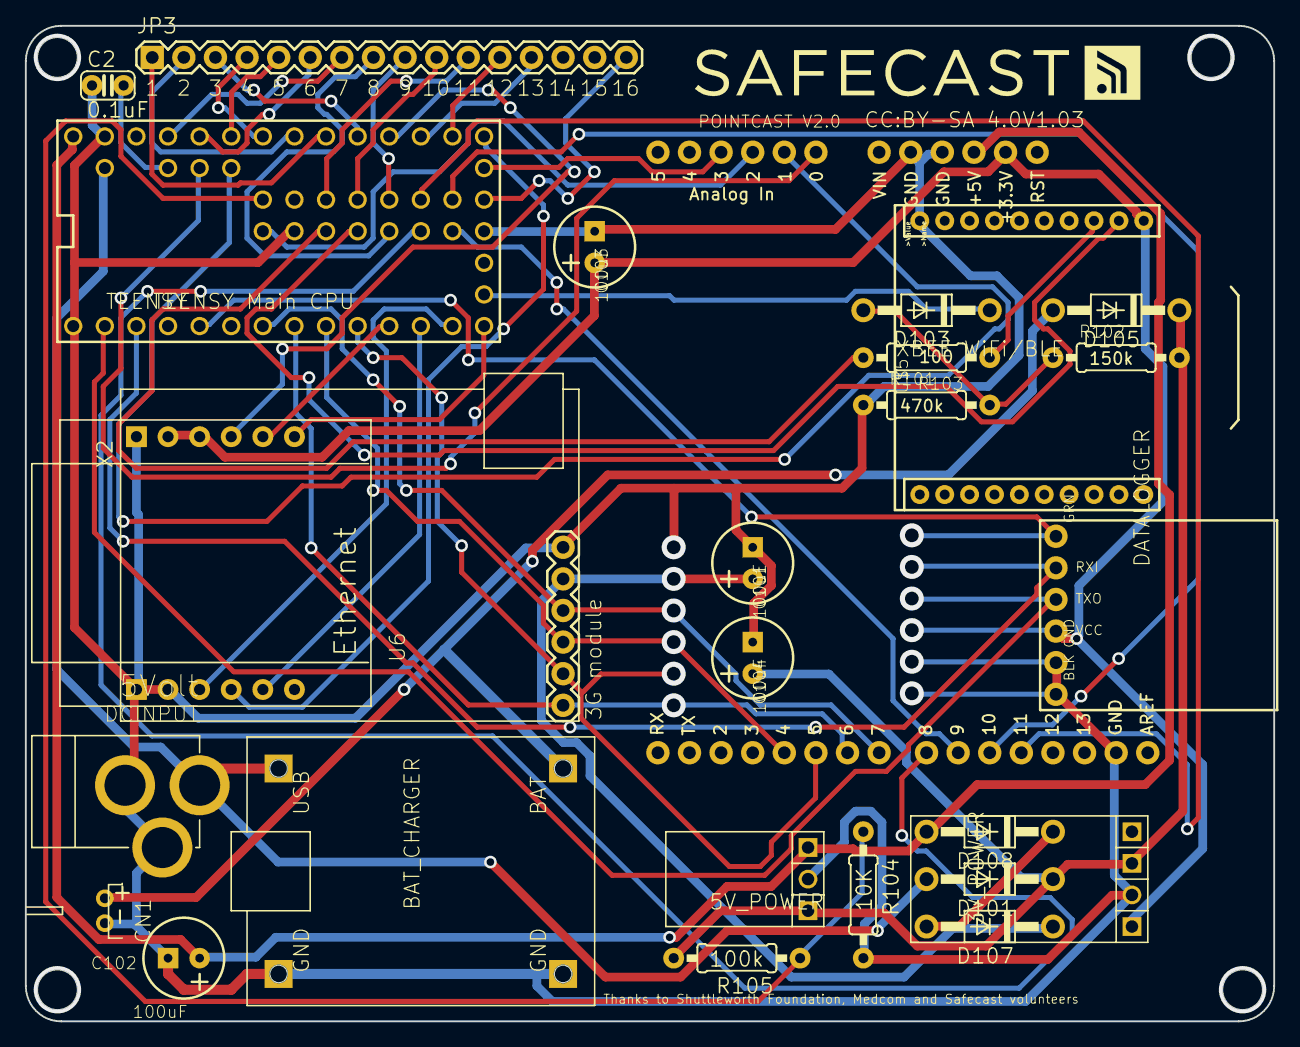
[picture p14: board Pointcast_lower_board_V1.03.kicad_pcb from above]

Board: 2 copper layers, 100.3 x 80.0 mm, 33 parts (0 on the bottom side), 36 nets.

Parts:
3V_POWER: POLOLU_D24VXAYV_HC
5V_POWER: POLOLU_S7V8F5
@HOLE0, @HOLE1, @HOLE2, @HOLE3: (no value)
BAT_CHARGER: TP4056_CHARGER; TP4056
C2: 0.1uF; C025-024X044
C101, C102, C103, C104: 100uF; CPOL-RADIAL-100UF-25V
CN1: JST-PH-2-THM-RA
D101, D103, D105, D107, D108: 1N4004; DO41-10
DATALOGGER: OPENLOG
DCINPUT: 5Volt; DC-21MM
FRAME1: FRAME-LEDGER; CREATIVE_COMMONS
JP3: 1X16
R101: 470k; 0207%2f10
R102: 150k; 0207%2f10
R103: 100; 0207%2f10
R104: 10K; 0207%2f10
R105: 100k; 0207%2f10
TEENSY: TEENSY Main CPU; TEENSY_3.0_ALLPINS
U6: Ethernet; WIZ820IO
U$5: XBEE WiFi/BLE; XBEE-SILK
U$10: SAFECAST_LOGO1
X2: 3G module; 1X06
X4: 3GS shield; DUEMILANOVE_SHIELD

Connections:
A10: TEENSY.A10, X4.A0
A11: TEENSY.A11, X4.A1
A12: TEENSY.A12, X4.A2
BAT: BAT_CHARGER.BAT, CN1.1, D105.A
D5: TEENSY.5, X2.4, X4.D7
D6: TEENSY.6, X2.1, X4.D6
D7: TEENSY.7, X2.3, X4.D4
D8: TEENSY.8, X2.2, X4.D5
D9: TEENSY.9, U6.J2.5
D10: TEENSY.10, U6.J1.5
D11: TEENSY.11, U6.J1.3
D12: TEENSY.12, U6.J2.6
D13: TEENSY.13, U6.J1.4
D26: JP3.8, TEENSY.26
D27: TEENSY.27, X4.D8
D28: TEENSY.28, X4.D9
D29: TEENSY.29, X4.D10
D30: TEENSY.30, X4.D11
D31: JP3.9, TEENSY.31
D32: JP3.10, TEENSY.32
D33: JP3.11, TEENSY.33
GND: 3V_POWER.G, 5V_POWER.G, BAT_CHARGER.GND, BAT_CHARGER.GND2, C2.1, C101.1, C102.1, C103.1, C104.1, CN1.2, DCINPUT.1, DCINPUT.3, R101.1, R104.2, TEENSY.AGND, TEENSY.GND, TEENSY.GND1, TEENSY.GND2, U6.J1.1, U6.J1.2, U6.J2.1, U$5.10, X2.6
unnamed: D103.C, TEENSY.VBAT
unnamed: D103.A, R101.2, R102.1
unnamed: R104.1, R105.1, TEENSY.A13
unnamed: R103.1, U$5.3
unnamed: C2.2, TEENSY.AREF
unnamed: D107.A, D108.C
unnamed: C101.2, D107.C, X2.5
PGM: JP3.16, TEENSY.PGM
PWRIN: 3V_POWER.I, 5V_POWER.I, C104.2, D101.C, D105.C, R102.2, R105.2
RXI: TEENSY.25, U$5.2
TXO: R103.2, TEENSY.24
VCC: 3V_POWER.O, C103.2, U6.J2.2, U6.J2.3, U$5.1, X4.3.3V
VDD: 5V_POWER.O, C102.2, D108.A, TEENSY.VIN, X4.5V
VUSB: D101.A, DCINPUT.2, TEENSY.VUSB

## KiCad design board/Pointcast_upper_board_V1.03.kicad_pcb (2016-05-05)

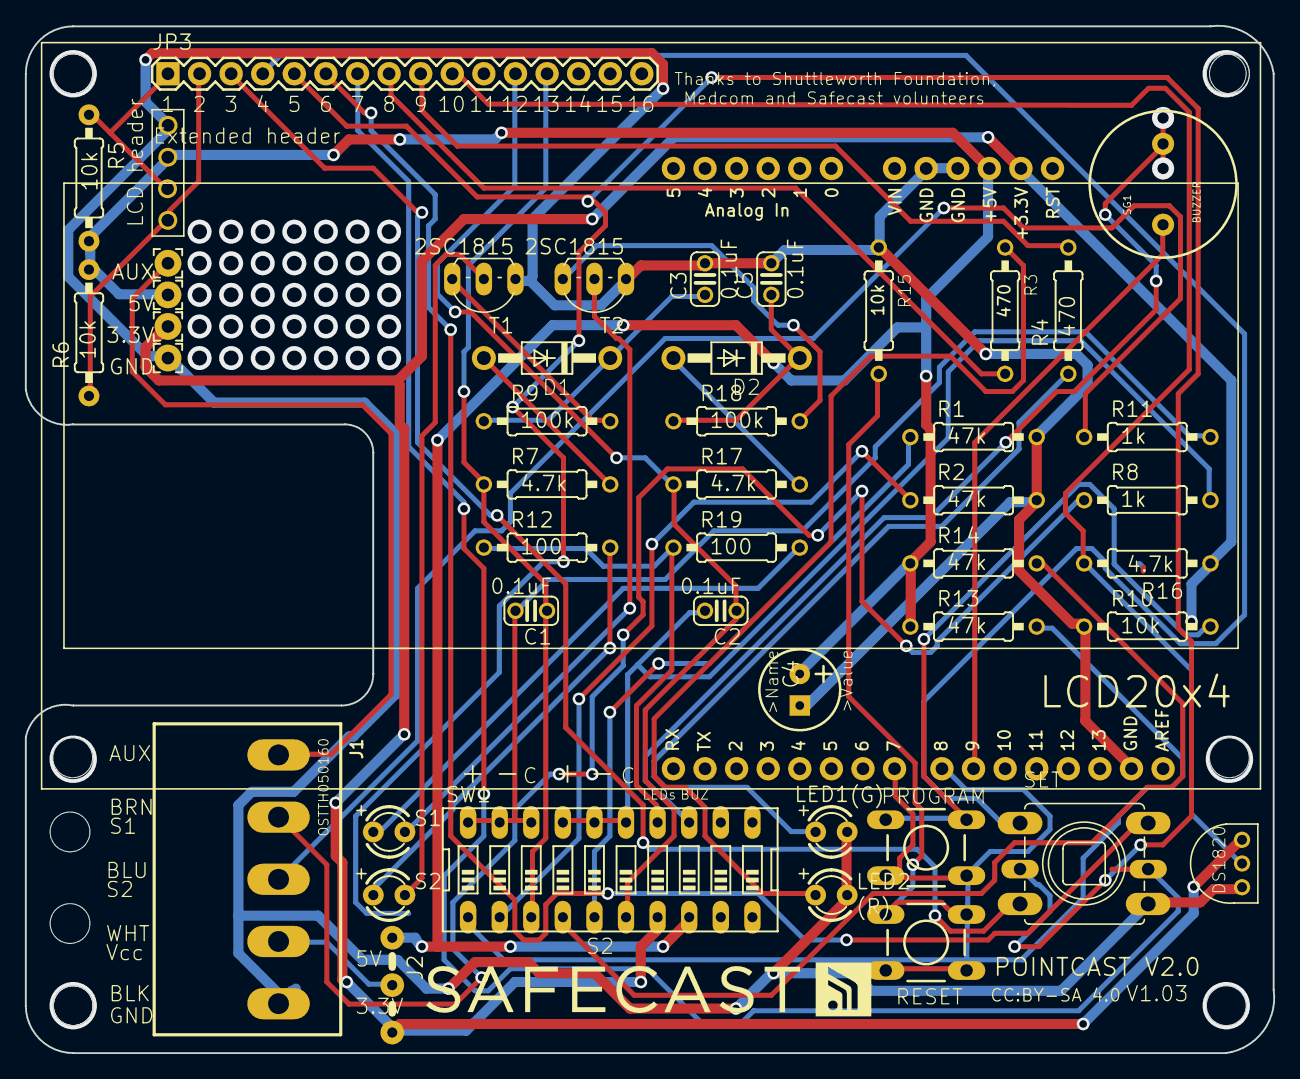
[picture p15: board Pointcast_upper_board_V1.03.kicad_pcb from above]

Board: 2 copper layers, 100.4 x 82.6 mm, 56 parts (0 on the bottom side), 42 nets.

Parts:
@HOLE0, @HOLE1, @HOLE2, @HOLE3, @HOLE4, @HOLE5, @HOLE6: (no value)
C1, C2, C3, C5: 0.1uF; C025-024X044
C4: 100uf; CPOL-RADIAL-100UF-25V
D1, D2: DO41-10
FRAME1: FRAME-LEDGER; CREATIVE_COMMONS
J1: OSTTH050160; EDSTL130-05
J2: 04C
JP3: Extended header; 1X16
LED1: (G); LED3MM
LED2: (R); LED3MM
PAD1: AUX; 2,15%2f1,0
PAD2: 5V; 2,15%2f1,0
PAD3: GND; 2,15%2f1,0
PAD4: 3.3V; 2,15%2f1,0
PROGRAM: DTS-6
R1, R2, R13, R14: 47k; 0207%2f10
R3, R4: 470; 0207%2f10
R5, R6, R10, R15: 10k; 0207%2f10
R7, R16, R17: 4.7k; 0207%2f10
R8, R11: 1k; 0207%2f10
R9, R18: 100k; 0207%2f10
R12, R19: 100; 0207%2f10
RESET: RESET; DTS-6
S1, S2: LED3MM
SET: SKQU
SG1: BUZZER; BUZZER-12MM
SW1: EDG-10
T1, T2: 2SC1815; TO92-ECB
TEMP: AVA_DS1820TO92; AVA_DS1820
U$10: SAFECAST_LOGO1
X1: LCD-HD447804-HOLES20X4-4HOLES; LCD-20X4-4HOLES
X3: 3GS shield; DUEMILANOVE_SHIELD

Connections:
BLUE: J1.2, R8.1
BROWN: J1.3, R11.1
D14: C2.1, JP3.12, R17.1, SW1.6
D15: C1.1, JP3.13, R7.1, SW1.3
D17: JP3.3, SET.DOWN
D20: JP3.4, SET.UP
D21: JP3.5, SET.LEFT
D26: JP3.8, R3.2
D31: JP3.9, R4.2
D32: JP3.10, R16.2, TEMP.DQ
GND: C3.2, C4.1, C5.2, J1.5, LED1.K, LED2.K, PAD3.1, R1.2, R2.2, R10.1, R15.1, T1.E, T2.E, TEMP.GND, X1.P$13
unnamed: SG1.+, SW1.13
unnamed: LED2.A, R3.1
unnamed: R14.2, SW1.4
unnamed: R12.1, R19.1, SW1.14
unnamed: R2.1, SW1.2
unnamed: R1.1, SW1.5
unnamed: J1.1, PAD1.1
unnamed: SG1.-, X3.D9
unnamed: PROGRAM.1, PROGRAM.2, R10.2
unnamed: PROGRAM.3, PROGRAM.4, X3.D7
unnamed: J1.4, J2.2
unnamed: C1.2, R11.2, SW1.18, SW1.19, SW1.20
unnamed: R13.2, SW1.1
unnamed: D1.A, R7.2
unnamed: C3.1, D1.C, R9.1
unnamed: LED1.A, R4.1
unnamed: R9.2, T1.B
unnamed: S2.K, T1.C
unnamed: R15.2, RESET.1, RESET.2
unnamed: RESET.3, RESET.4, X3.D8
unnamed: R12.2, S2.A
unnamed: D2.A, R17.2
unnamed: C5.1, D2.C, R18.1
unnamed: R18.2, T2.B
unnamed: S1.K, T2.C
unnamed: R19.2, S1.A
unnamed: C2.2, R8.2, SW1.15, SW1.16, SW1.17
SCA: JP3.1, R5.1, X1.P$15
SCL: JP3.2, R6.1, X1.P$16
VCC: J2.3, PAD4.1, R16.1, SW1.7, TEMP.VDD, X3.3.3V
VDD: C4.2, J2.1, PAD2.1, R5.2, R6.2, R13.1, R14.1, SW1.8, X1.P$14, X3.5V

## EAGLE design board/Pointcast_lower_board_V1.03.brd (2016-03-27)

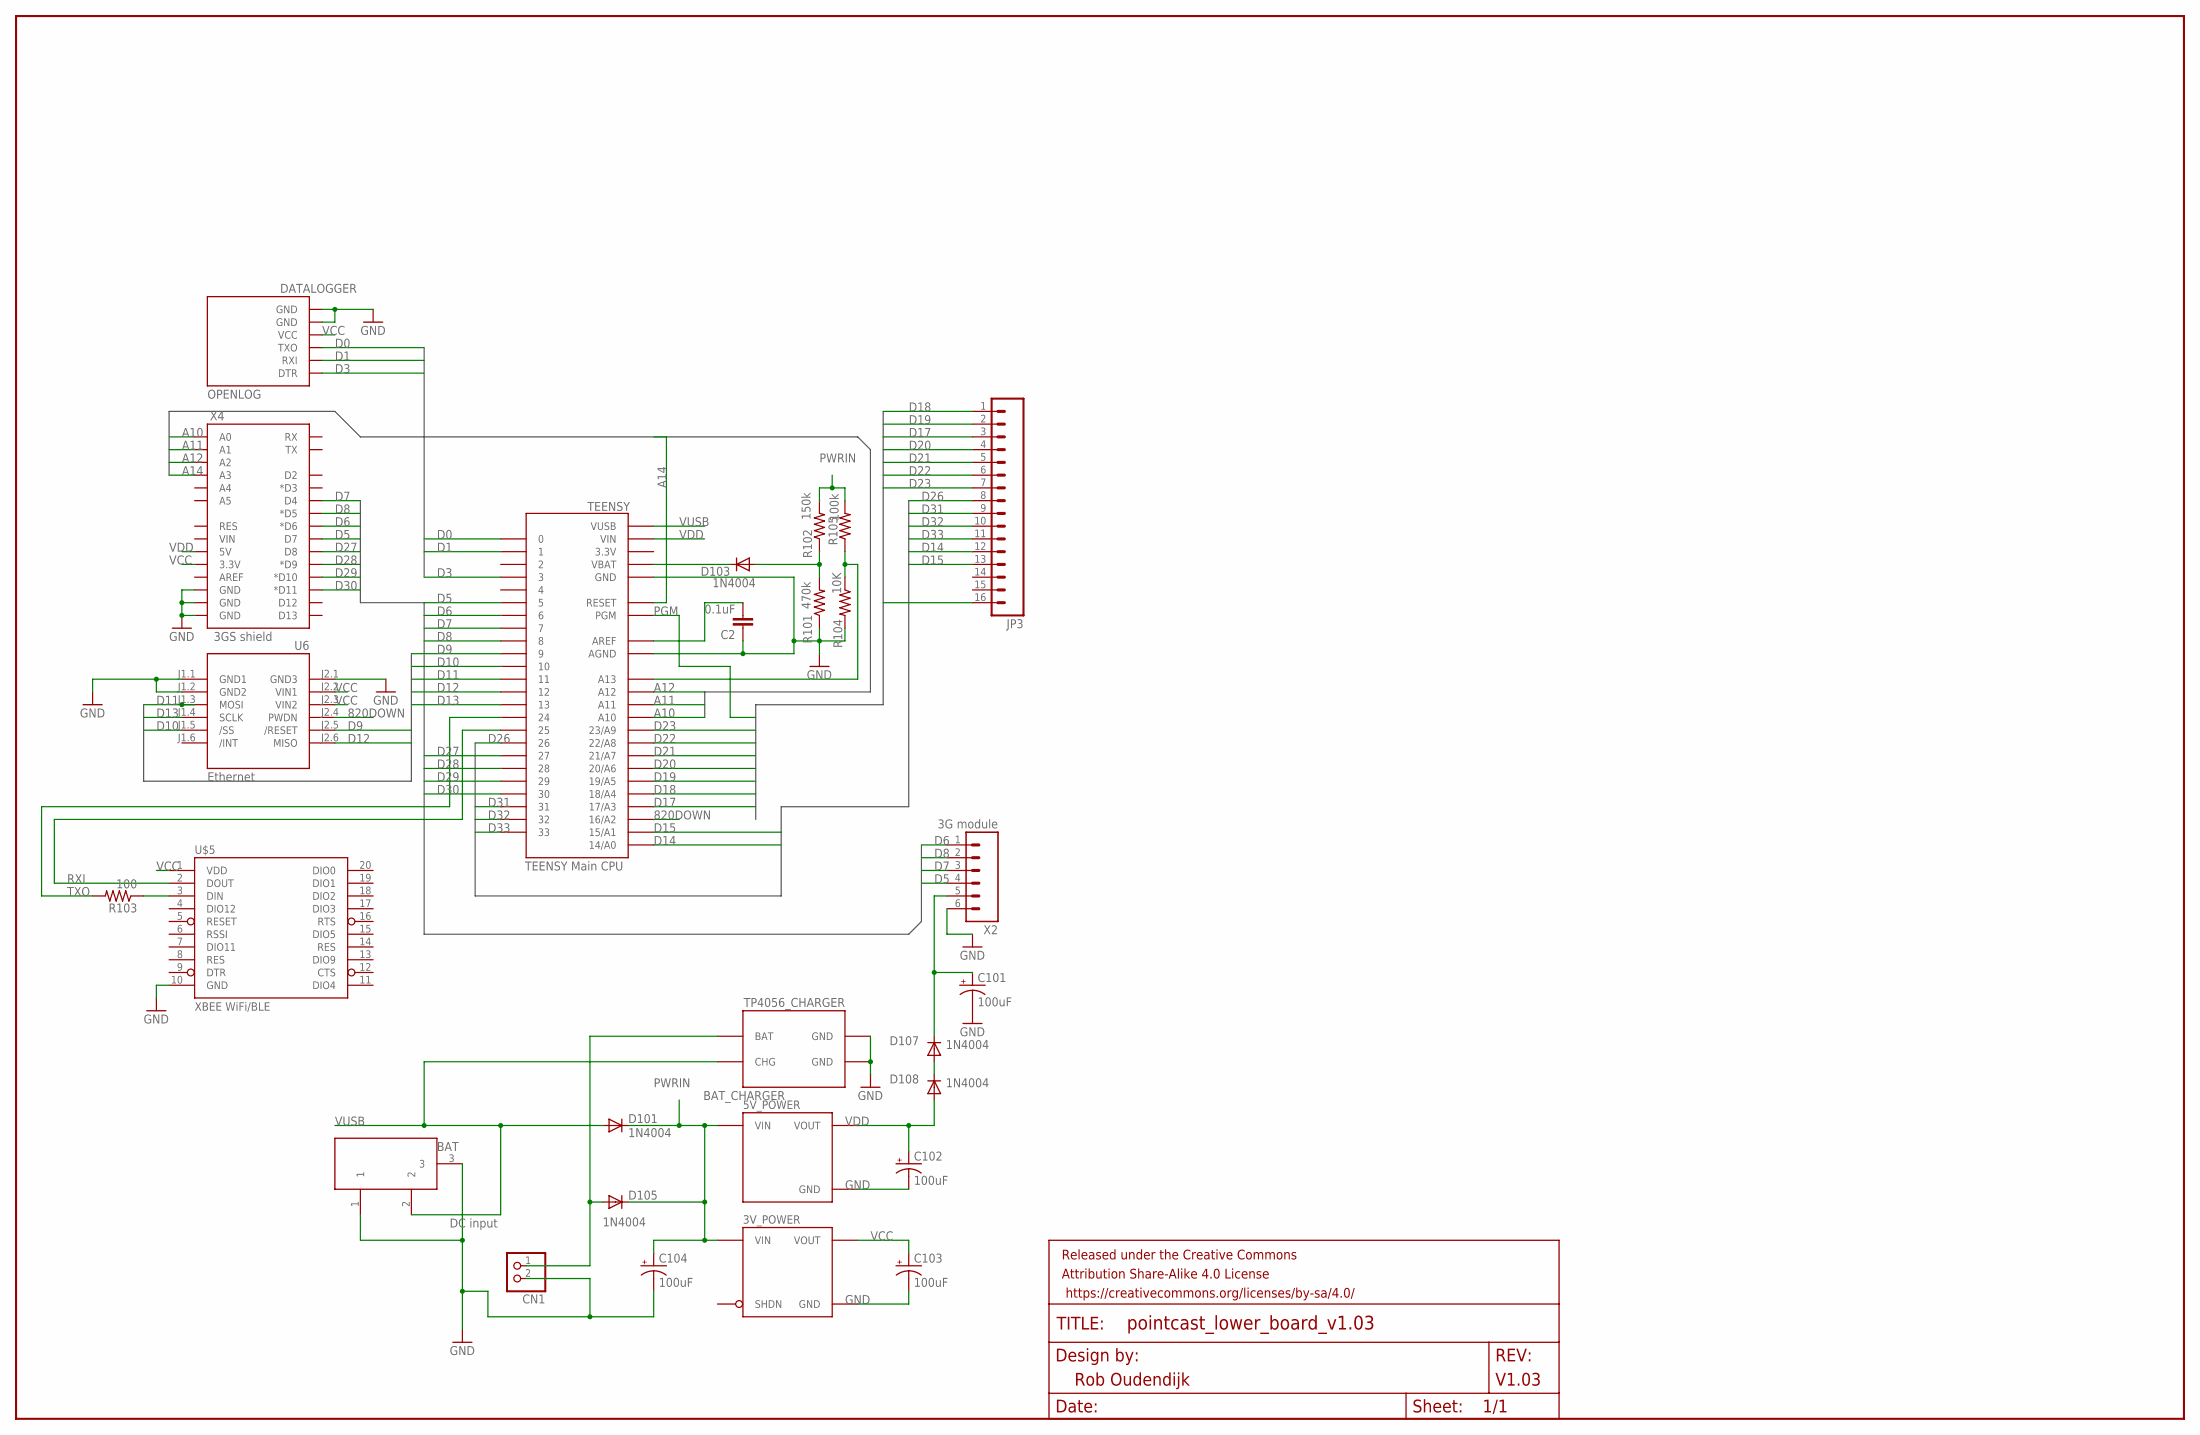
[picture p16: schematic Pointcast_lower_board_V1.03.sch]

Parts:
3V_POWER: POLOLU_D24V3AXV; POLOLU_D24VXAYV_HC
5V_POWER: POLOLU_S7V8F5
BAT_CHARGER: TP4056_CHARGER; TP4056
C2: 0.1uF; C025-024X044
C101, C102, C103, C104: 100uF; CPOL-RADIAL-100UF-25V
CN1: JST_2PIN-THM-RA; JST-PH-2-THM-RA
D101, D103, D105, D107, D108: 1N4004; DO41-10
DATALOGGER: OPENLOG
DCINPUT: 5Volt; DC-21MM
FRAME1: FRAME-LEDGER; CREATIVE_COMMONS
JP3: M16PTH; 1X16
R101: 470k; 0207/10
R102: 150k; 0207/10
R103: 100; 0207/10
R104: 10K; 0207/10
R105: 100k; 0207/10
TEENSY: TEENSY Main CPU; TEENSY_3.0_ALLPINS
U6: Ethernet; WIZ820IO
U$5: XBEE WiFi/BLE; XBEE-SILK
X2: 3G module; 1X06
X4: 3GS shield; DUEMILANOVE_SHIELD

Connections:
820DOWN: TEENSY.16/A2, U6.J2.4 (PWDN)
A10: TEENSY.A10, X4.A0
A11: TEENSY.A11, X4.A1
A12: TEENSY.A12, X4.A2
A14: TEENSY.RESET, X4.A3
BAT: BAT_CHARGER.BAT, CN1.1 (2), D105.A
D0: DATALOGGER.JP1$3 (TXO), TEENSY.0
D1: DATALOGGER.JP1$2 (RXI), TEENSY.1
D3: DATALOGGER.JP1$1 (DTR), TEENSY.3
D5: TEENSY.5, X2.4, X4.D7
D6: TEENSY.6, X2.1, X4.D6 (*D6)
D7: TEENSY.7, X2.3, X4.D4
D8: TEENSY.8, X2.2, X4.D5 (*D5)
D9: TEENSY.9, U6.J2.5 (/RESET)
D10: TEENSY.10, U6.J1.5 (/SS)
D11: TEENSY.11, U6.J1.3 (MOSI)
D12: TEENSY.12, U6.J2.6 (MISO)
D13: TEENSY.13, U6.J1.4 (SCLK)
D14: JP3.12, TEENSY.14/A0
D15: JP3.13, TEENSY.15/A1
D17: JP3.3, TEENSY.17/A3
D18: JP3.1, TEENSY.18/A4
D19: JP3.2, TEENSY.19/A5
D20: JP3.4, TEENSY.20/A6
D21: JP3.5, TEENSY.21/A7
D22: JP3.6, TEENSY.22/A8
D23: JP3.7, TEENSY.23/A9
D26: JP3.8, TEENSY.26
D27: TEENSY.27, X4.D8
D28: TEENSY.28, X4.D9 (*D9)
D29: TEENSY.29, X4.D10 (*D10)
D30: TEENSY.30, X4.D11 (*D11)
D31: JP3.9, TEENSY.31
D32: JP3.10, TEENSY.32
D33: JP3.11, TEENSY.33
GND: 3V_POWER.G (GND), 5V_POWER.G (GND), BAT_CHARGER.GND, BAT_CHARGER.GND2 (GND), C2.1, C101.1 (-), C102.1 (-), C103.1 (-), C104.1 (-), CN1.2 (1), DATALOGGER.JP1$5 (GND), DATALOGGER.JP1$6 (GND), DCINPUT.1, DCINPUT.3, R101.1, R104.2, TEENSY.AGND, TEENSY.GND, TEENSY.GND1 (GND), TEENSY.GND2 (GND), U6.J1.1 (GND1), U6.J1.2 (GND2), U6.J2.1 (GND3), U$5.10 (GND), X2.6, X4.GND@0 (GND), X4.GND@1 (GND), X4.GND@2 (GND)
unnamed: D103.C, TEENSY.VBAT
unnamed: D103.A, R101.2, R102.1
unnamed: R104.1, R105.1, TEENSY.A13
unnamed: R103.1, U$5.3 (DIN)
unnamed: C2.2, TEENSY.AREF
unnamed: D107.A, D108.C
unnamed: C101.2 (+), D107.C, X2.5
PGM: JP3.16, TEENSY.PGM
PWRIN: 3V_POWER.I (VIN), 5V_POWER.I (VIN), C104.2 (+), D101.C, D105.C, R102.2, R105.2
RXI: TEENSY.25, U$5.2 (DOUT)
TXO: R103.2, TEENSY.24
VCC: 3V_POWER.O (VOUT), C103.2 (+), DATALOGGER.JP1$4 (VCC), U6.J2.2 (VIN1), U6.J2.3 (VIN2), U$5.1 (VDD), X4.3.3V
VDD: 5V_POWER.O (VOUT), C102.2 (+), D108.A, TEENSY.VIN, X4.5V
VUSB: BAT_CHARGER.CHARGER (CHG), D101.A, DCINPUT.2, TEENSY.VUSB

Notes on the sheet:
DC input

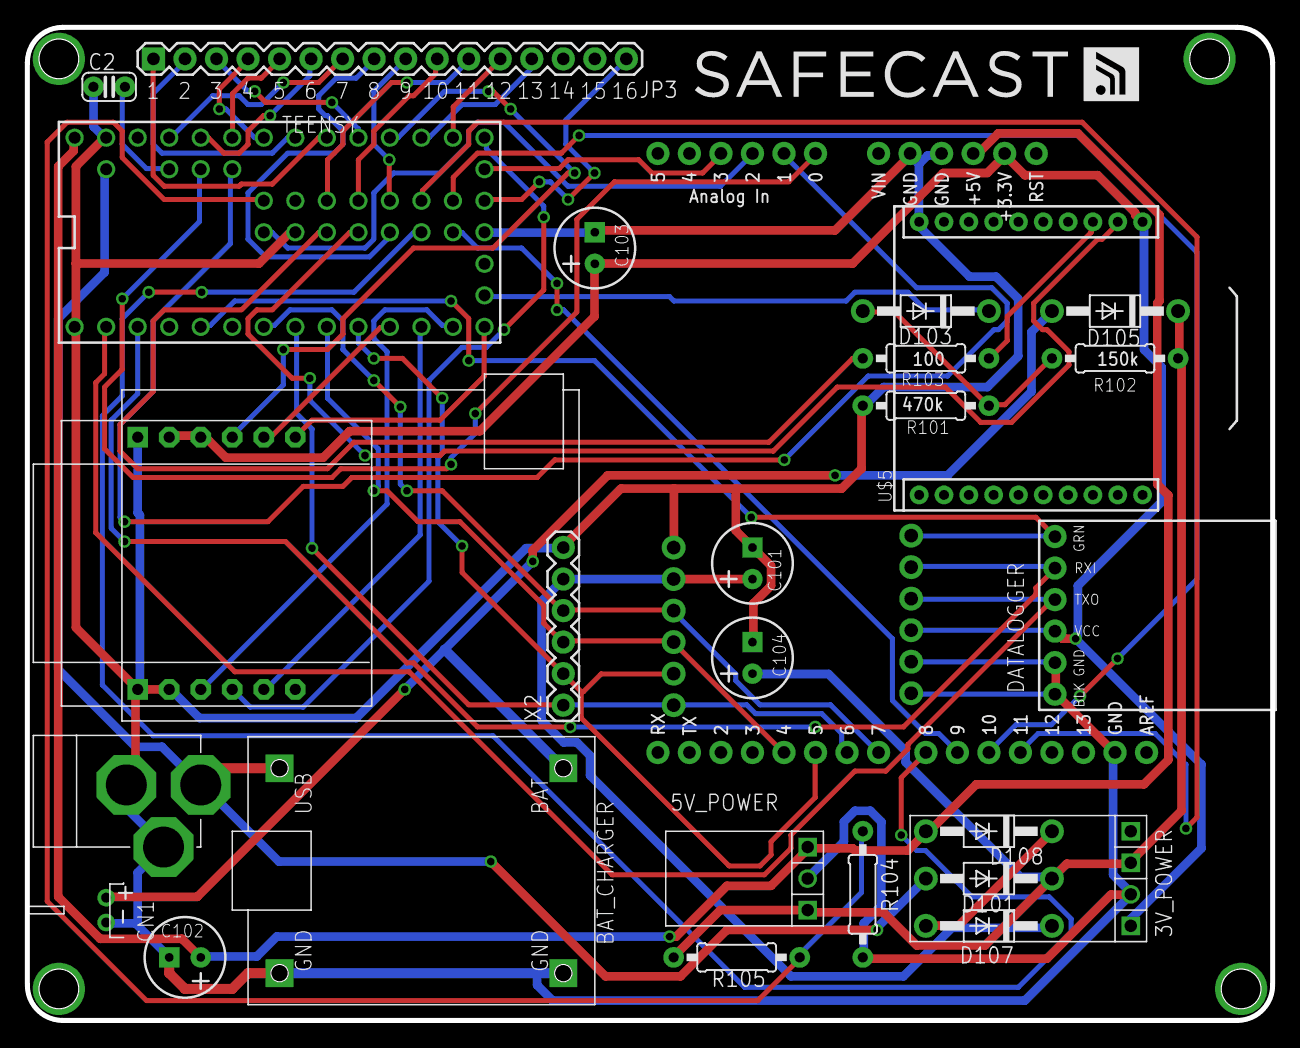
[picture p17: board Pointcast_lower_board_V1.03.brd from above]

Board: 2 copper layers, 100.3 x 80.0 mm, 29 parts (0 on the bottom side), 50 nets.

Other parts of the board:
U$10: SAFECAST_LOGO1

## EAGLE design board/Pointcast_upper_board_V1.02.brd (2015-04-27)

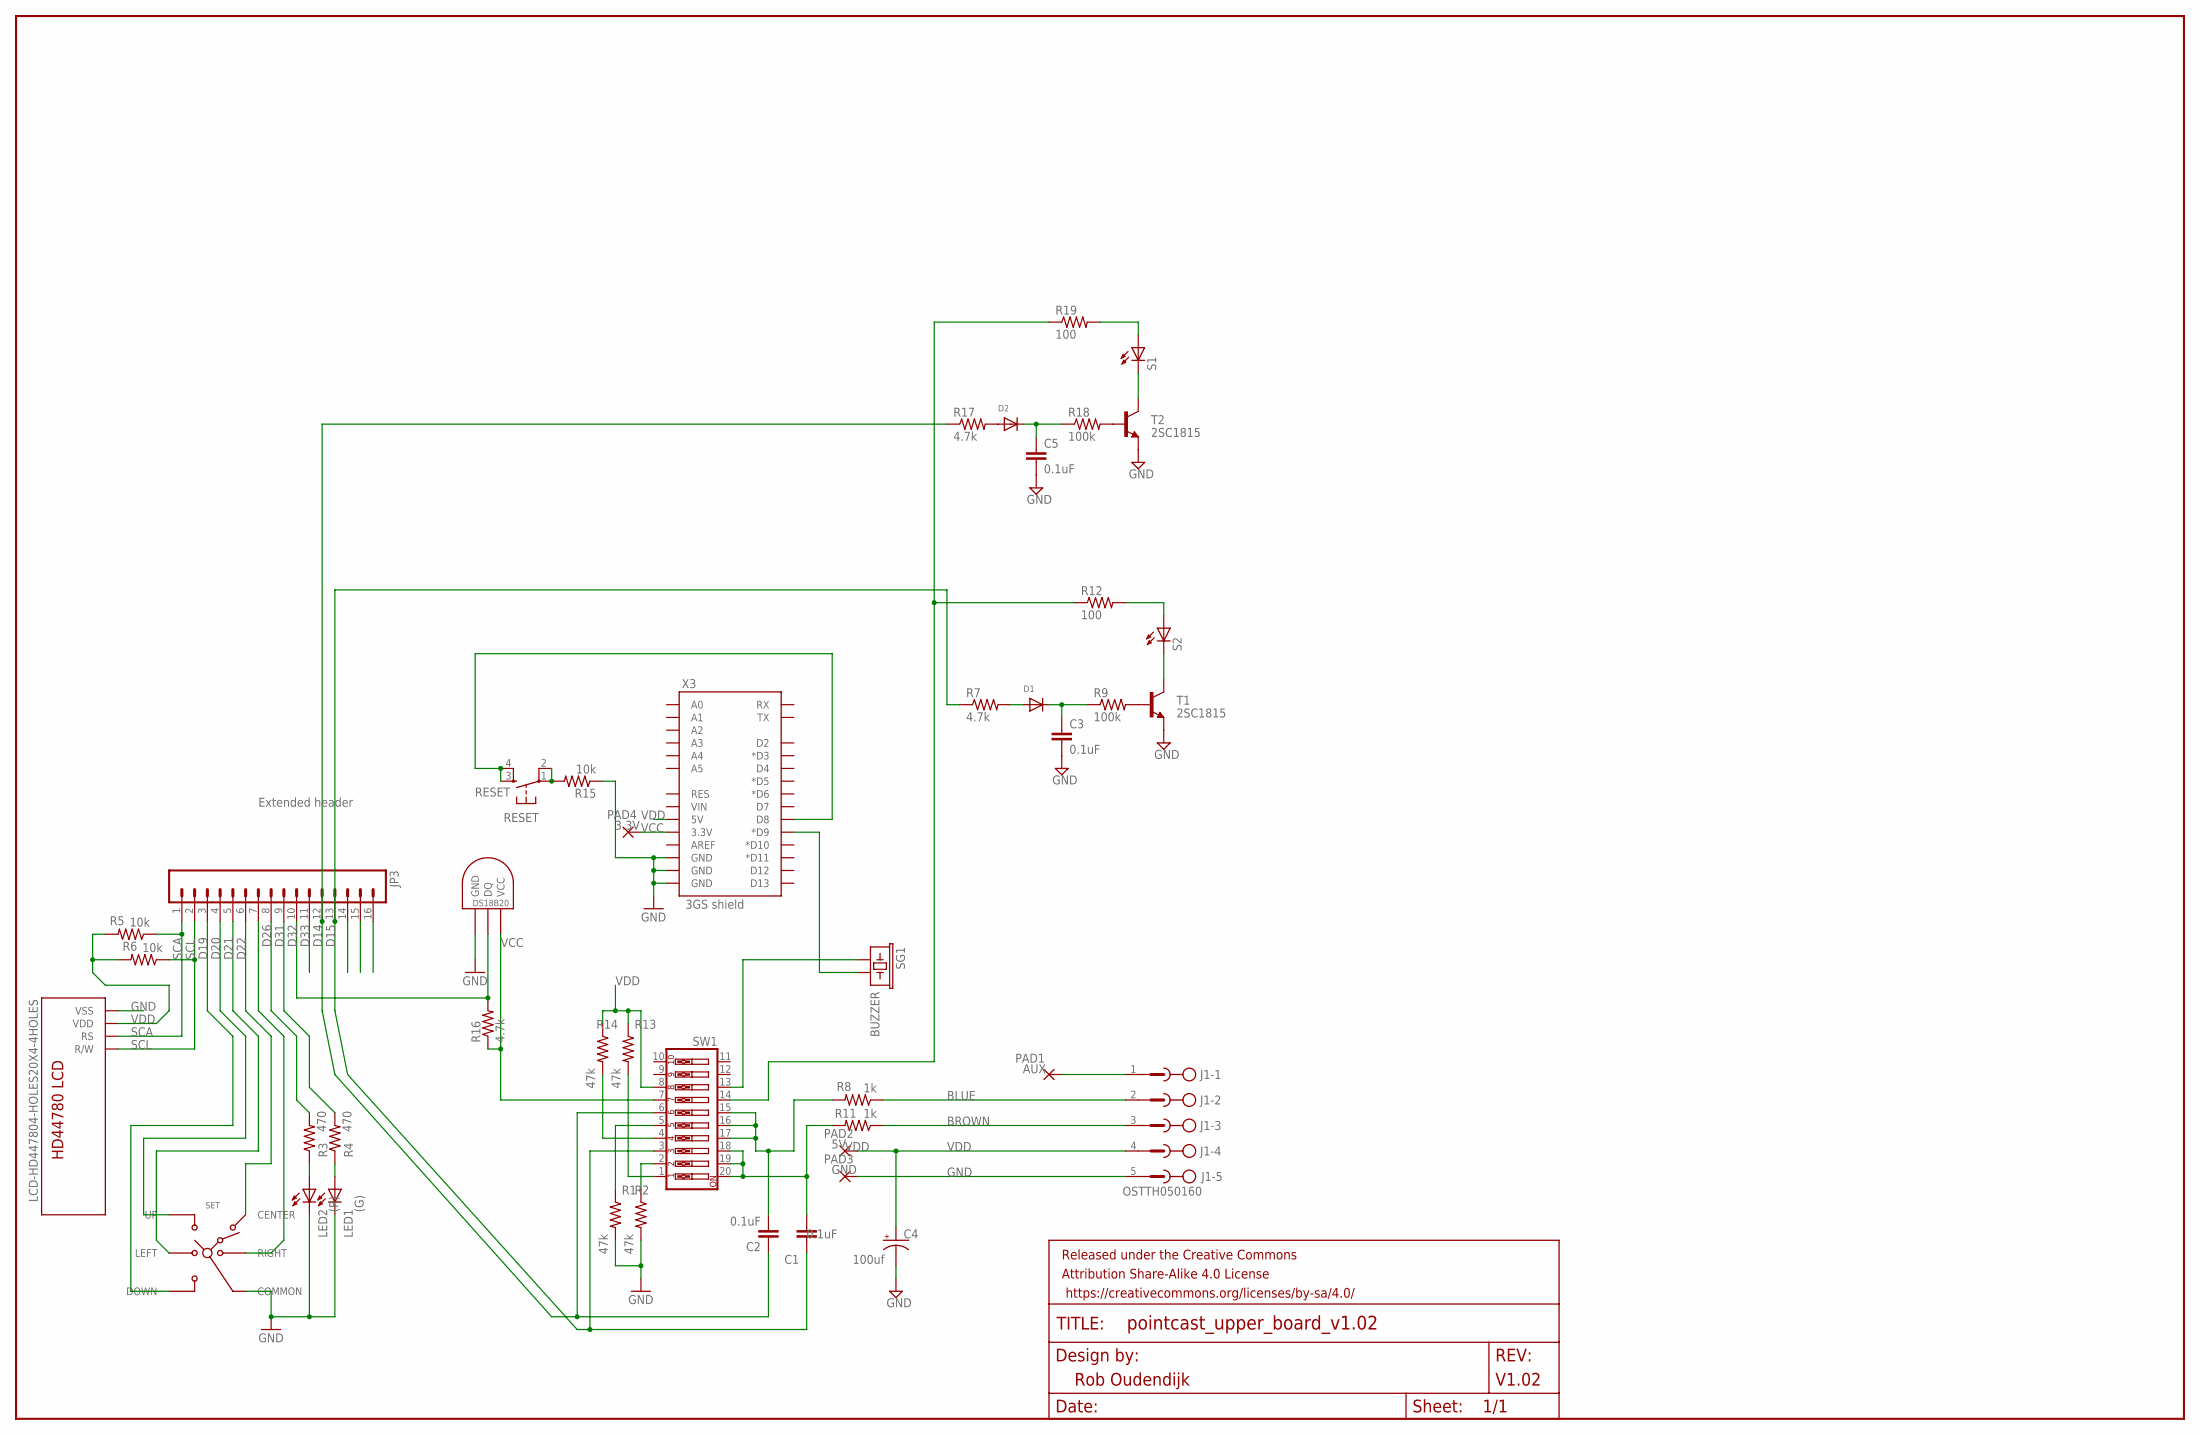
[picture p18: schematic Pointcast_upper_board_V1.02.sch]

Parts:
C1, C2, C3, C5: 0.1uF; C025-024X044
C4: 100uf; CPOL-RADIAL-100UF-25V
D1, D2: DIODEDIODE_BIG; DO41-10
FRAME1: FRAME-LEDGER; CREATIVE_COMMONS
J1: OSTTH050160; EDSTL130-05
JP3: Extended header; 1X16
LED1: (G); LED3MM
LED2: (R); LED3MM
PAD1: AUX; 2,15/1,0
PAD2: 5V; 2,15/1,0
PAD3: GND; 2,15/1,0
PAD4: 3.3V; 2,15/1,0
R1, R2, R13, R14: 47k; 0207/10
R3, R4: 470; 0207/10
R5, R6, R15: 10k; 0207/10
R7, R16, R17: 4.7k; 0207/10
R8, R11: 1k; 0207/10
R9, R18: 100k; 0207/10
R12, R19: 100; 0207/10
RESET: RESET; DTS-6
S1, S2: LED3MM
SET: SKQUCAA010; SKQU
SG1: BUZZER; BUZZER-12MM
SW1: SW_DIP-10; EDG-10
T1, T2: 2SC1815; TO92-ECB
TEMP: AVA_DS1820TO92; AVA_DS1820
X1: LCD-HD447804-HOLES20X4-4HOLES; LCD-20X4-4HOLES
X3: 3GS shield; DUEMILANOVE_SHIELD

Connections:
BLUE: J1.2, R8.1
BROWN: J1.3, R11.1
D14: C2.1, JP3.12, R17.1, SW1.6
D15: C1.1, JP3.13, R7.1, SW1.3
D19: JP3.3, SET.DOWN
D20: JP3.4, SET.UP
D21: JP3.5, SET.LEFT
D22: JP3.6, SET.CENTER
D26: JP3.8, R3.2
D31: JP3.9, R4.2
D32: JP3.10, R16.2, TEMP.DQ
D33: JP3.11
GND: C3.2, C4.1 (-), C5.2, J1.5, LED1.K (C), LED2.K (C), PAD3.1, R1.2, R2.2, R15.1, SET.COMMON, T1.E, T2.E, TEMP.GND, X1.P$13 (VSS), X3.GND@0 (GND), X3.GND@1 (GND), X3.GND@2 (GND)
unnamed: SG1.+ (1), SW1.13
unnamed: LED2.A, R3.1
unnamed: R14.2, SW1.4
unnamed: R12.1, R19.1, SW1.14
unnamed: R2.1, SW1.2
unnamed: R1.1, SW1.5
unnamed: J1.1, PAD1.1
unnamed: SG1.- (2), X3.D9 (*D9)
unnamed: C1.2, R11.2, SW1.18, SW1.19, SW1.20
unnamed: R13.2, SW1.1
unnamed: D1.A, R7.2
unnamed: C3.1, D1.C, R9.1
unnamed: LED1.A, R4.1
unnamed: R9.2, T1.B
unnamed: S2.K (C), T1.C
unnamed: R15.2, RESET.1, RESET.2
unnamed: RESET.3, RESET.4, X3.D8
unnamed: R12.2, S2.A
unnamed: D2.A, R17.2
unnamed: C5.1, D2.C, R18.1
unnamed: R18.2, T2.B
unnamed: S1.K (C), T2.C
unnamed: R19.2, S1.A
unnamed: C2.2, R8.2, SW1.15, SW1.16, SW1.17
S$5: JP3.7, SET.RIGHT
SCA: JP3.1, R5.1, X1.P$15 (RS)
SCL: JP3.2, R6.1, X1.P$16 (R/W)
VCC: PAD4.1, R16.1, SW1.7, TEMP.VDD (VCC), X3.3.3V
VDD: C4.2 (+), J1.4, PAD2.1, R5.2, R6.2, R13.1, R14.1, SW1.8, X1.P$14 (VDD), X3.5V

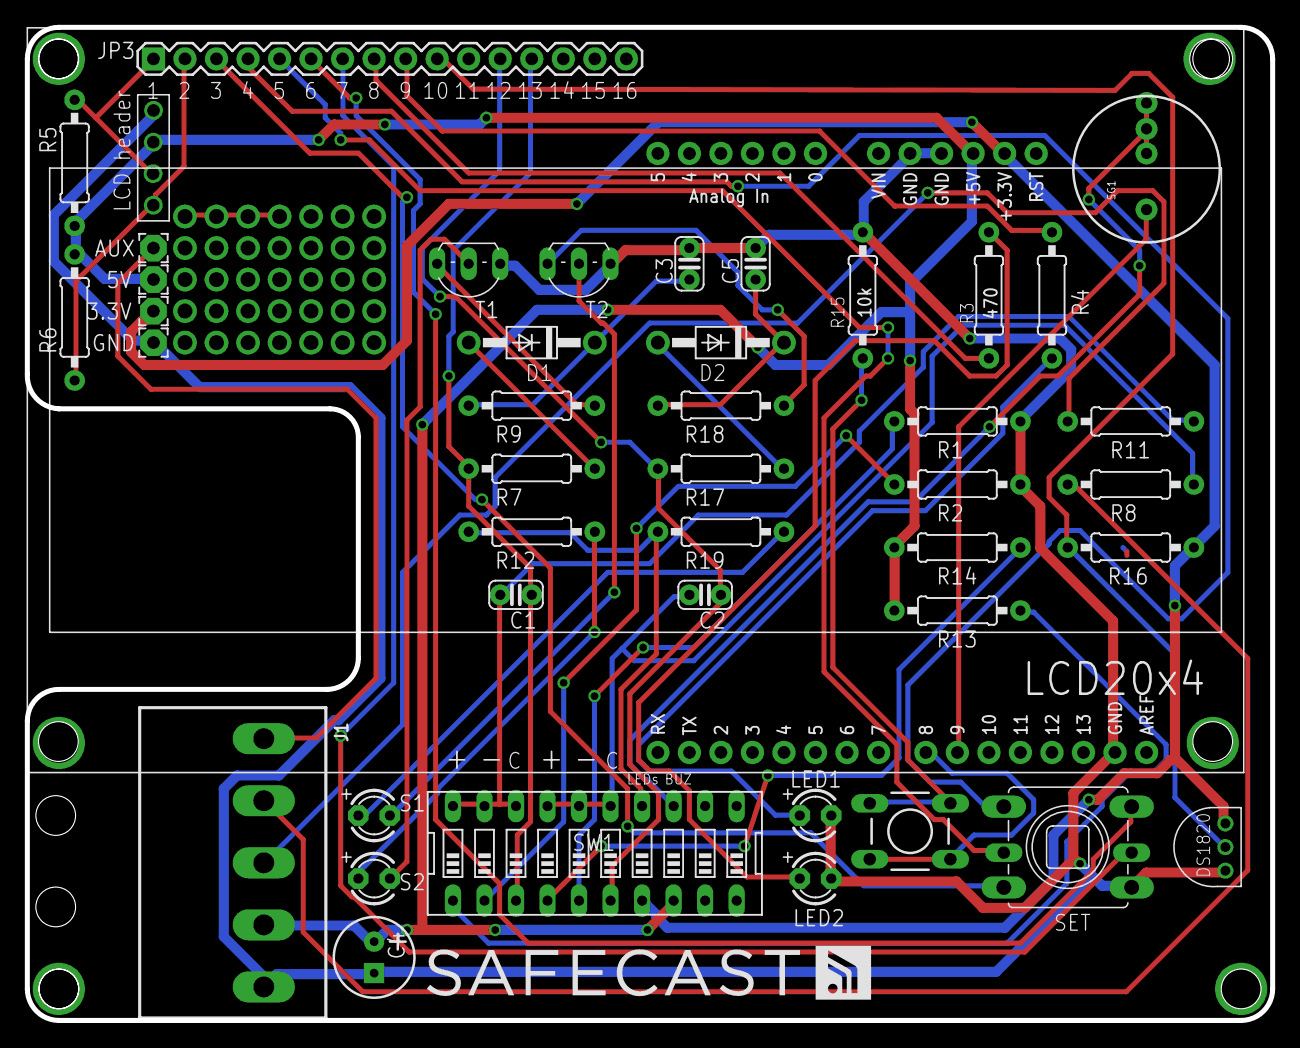
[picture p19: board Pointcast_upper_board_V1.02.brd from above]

Board: 2 copper layers, 100.3 x 80.0 mm, 46 parts (0 on the bottom side), 41 nets.

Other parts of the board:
U$10: SAFECAST_LOGO1

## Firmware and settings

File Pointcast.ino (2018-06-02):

/*
    A fixed position Safecast device for Radiation measurement.

   Copyright (c) 2015, Safecast

   All rights reserved.

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
   THIS SOFTWARE IS PROVIDED BY THE COPYRIGHT HOLDERS AND CONTRIBUTORS "AS IS" AND
   ANY EXPRESS OR IMPLIED WARRANTIES, INCLUDING, BUT NOT LIMITED TO, THE IMPLIED
   WARRANTIES OF MERCHANTABILITY AND FITNESS FOR A PARTICULAR PURPOSE ARE
   DISCLAIMED. IN NO EVENT SHALL <COPYRIGHT HOLDER> BE LIABLE FOR ANY
   DIRECT, INDIRECT, INCIDENTAL, SPECIAL, EXEMPLARY, OR CONSEQUENTIAL DAMAGES
   (INCLUDING, BUT NOT LIMITED TO, PROCUREMENT OF SUBSTITUTE GOODS OR SERVICES;
   LOSS OF USE, DATA, OR PROFITS; OR BUSINESS INTERRUPTION) HOWEVER CAUSED AND
   ON ANY THEORY OF LIABILITY, WHETHER IN CONTRACT, STRICT LIABILITY, OR TORT
   (INCLUDING NEGLIGENCE OR OTHERWISE) ARISING IN ANY WAY OUT OF THE USE OF THIS
   SOFTWARE, EVEN IF ADVISED OF THE POSSIBILITY OF SUCH DAMAGE.


History Versions:

2015-04-05 V2.4.9 delay for switching off LEDs
2015-04-07 V2.6.0 merged code with 3G
2015-04-07 V2.6.1 beeper setup and code cleaning(need jumper from D10 in Arduino shield (is pin D27)to A3)
2015-04-08 V2.6.3 setup for measuring voltage on A13
2015-04-08 V2.6.4 made switch for sending to dev or API
2015-04-14 V2.6.6 added heart beat on green LED and reading setup for files
2015-04-19 V2.6.7 added setup files now 1024 byte possible . added setup variables
2015-04-20 V2.6.8 added device ID, startup screen change, header for file format changed to NGRDD
2015-04-23 V2.6.9 added second line to SDcard logging for added status NNXSTS, added menus
2015-04-23 V2.7.0 renamed Pointcast
2015-04-28 V2.7.1 moved  startup 3G into send string, battery voltage report corrected for Teensy.
2015-04-30 V2.7.2 Added temperature setup for DS18B20 (disabled at the moment) setup screens
2015-05-05 V2.7.3 Added Joy stick setup. Added Height. Fixed lot/lan sending information on Ethernet
2015-05-08 V2.7.4 Added new screens for setup and error reporting
2015-05-09 V2.7.5 Changed startup name
2015-05-10 V2.7.6 Added Red LED warning on SDcard and Sensor fails, renamed SDcard files and updates headers
2015-05-11 V2.7.7 Updates headers. 3G display and header setup same as Ethernet card
2015-05-12 V2.7.8 Moved SDcard screen before time screen
2015-05-16 V2.7.9 Added Joystick interaction. Key down startup 1/5 of normal time. Prepare joy stick enter key (push down) for other functions.
2015-05-17 V2.8.0 Changed startup screen to be faster with 1 second display if joystick in pressed down. Blink the heartbeat LED for 1 sec.
2015-05-18 V2.8.1 Setup NTP for automatic update time on Ethernet.
2015-05-19 V2.8.2 Fixed first display readings of CPM (was too high)
2015-05-19 V2.8.3 Fixed 3G not starting up due to Ethernet settings.
2015-05-22 V2.8.4 Auto gateway setup (two gateways at the moment)
2015-05-22 V2.8.5 Display RSSI level in 3G.
2015-05-23 V2.8.6 SDCard RSSI level saved in 3G.
2015-05-30 V2.8.7 Menu updated.
2015-05-30 V2.8.8 Menu loop remake
2015-05-31 V2.8.9 Logfile name fix
2015-05-31 V2.9.0 Sending data through indextest_extra.php on 107.161.164.166 with no time-stamping and with extra information
2015-06-04 V2.9.1 Setup for fast sens mode selectable from SDcard with the "trb" option
2015-06-08 V2.9.2 Temperature setup truncated API key, battery/power setup changed.
2015-06-10 V2.9.3 Added skip sdcard init on one time pass. uSv/H changed to uSH..menu stat prepared...
2015-06-17 V2.9.4  Fixed second line temperature and batter logging on SDcard
2015-06-17 V2.9.5  3G second line recoding for SDcard fixes
2015-06-19 V2.9.6  Changed file naming SDCard
2015-06-20 V2.9.7  more fixed 3G second line
2015-06-21 V2.9.8  Switch between API and Dev sending through sdcard.
2015-06-22 V2.9.9  DEV status is displayed on LCD
2015-06-22 V3.0.0  Second line for extra information fix (final)
2015-06-25 V3.0.1  Device Type ID on SDCard and the API setup for Device typing LND7317 is 129 and LND712 is 130
2015-06-25 V3.0.2  Added height for dev to measurements.
2015-06-25 V3.0.3  Fixes for SDcard reading and Network startup
2015-06-25 V3.0.4  RTC tests moved after network startup
2015-07-27 V3.0.5  Setup for kcpm
2015-07-30 V3.0.6  Setup for logic for sending data with deviceType ID
2015-08-15 V3.0.7  Fixed CPM2 bug in display
2015-08-16 V3.0.8  3G RTC and display setup changed
2015-08-18 V3.0.9  Voltage display adjusted for volage drop over D103 lower board
2015-08-18 V3.1.0  Switched Teensy to internal ref mode for voltage measurements
2015-08-21 V3.1.1  Added devicetype_id to send sting inside measurement
2015-08-25 V3.1.2  MACid reading from SDcard and programming
2015-08-25 V3.1.3  SDcard fail lcd display
2015-08-25 V3.1.4  Voltage display direct without diode compensation and  3G displays carrier
2015-08-25 V3.1.5  Fixed always two digit display Ethernet Mac
2015-08-25 V3.1.6  Fixed Ethernet hang bug.
2015-08-25 V3.1.7  Fixed RTC bug.
2015-08-26 V3.1.8  Fixed Ethernet display hang on scroll back bug
2015-08-27 V3.1.9  Fixes for sending Ethernet
2015-09-01 V3.2.0  Fixes for variables listing data.
2015-09-04 V3.2.1  Fixes for failing SDcard data is still send
2015-09-05 V3.2.2  Sending DeviceType_ID
2015-09-06 V3.2.3  3G display setting changed
2015-09-06 V3.2.4  Set audio alarms for failing to connect for 3G and Ethernet on sending
2015-09-12 V3.2.5  Setup fails for Ethernet connections FAIL=1 means sensor 1 fails to send .. FAIL=2 means sensor 2 fails to send ....added delay for 3G sensing between sensors
2015-09-12 V3.2.6  Setup S1peak and S2peak and setup for uptime of sensor
2015-09-15 V3.2.7  Terminal displays last failure
2015-09-19 V3.2.8  Single sensor setup displaying no error on sensor test
2015-09-19 V3.2.9  Reset every week on Saturday 9:30am (UTC)
2015-10-03 V3.3.0  Beep 3 times and some display errors fix
2015-10-09 V3.3.1  Added longer delay for 3G sending second sensor
2015-10-09 V3.3.2  Fixed display failed error 3G.
2015-11-14 V3.3.3  Changed the way 3G connects to APN
2015-11-16 V3.3.4  Fixed display failed error 3G.
2015-11-16 V3.3.5  EEprom clearing on enter of joystick at system screen.
2015-11-17 V3.3.6  Switch off fail led by enter joy switch on main screen
2015-11-21 V3.3.7  Fixed display failed error 3G.
2015-11-24 V3.3.8  Fixed display failed error 3G.
2015-12-03 V3.3.9  Added dose storage for EEProm.
2015-12-09 V3.4.0  Stores total counts in EEprom
2015-12-16 V3.4.1  fixes fails display
2015-12-31 V3.4.2  Ethernet fixes fails display
2016-01-05 V3.4.3  Change parameters in 3GIM for longer timeout of network and setup for 1024 body lenght
2016-01-07 V3.4.4  Changed delays in 3GIM for stability
2016-01-08 V3.4.5  Error messages fixed
2016-01-15 V3.4.6  httpPost fixes for 3G
2016-01-15 V3.4.7  serial confirm messages fix for 3G
2016-01-24 V3.4.8  added code for switching temperature sensor
2016-01-26 V3.4.9  changed 3G send way by restarting 3G module every time send.
2016-02-01 V3.5.0  Added Alarm function.
2016-02-15 V3.5.1  3G fast reset
2016-02-28 V3.5.8  reset after 5 times
2016-03-02 V3.5.9  added code for correct data login name on SDcard.
2016-03-03 V3.6.0  Ethernet detect messages on fail
2016-03-05 V3.6.3  redone menus
2016-03-05 V3.6.4  Fixed time issues.
2016-03-06 V3.6.5  Weekly restart redone
2016-03-08 V3.6.6  clean out code
2016-03-09 V3.6.7  RTC menu
2016-03-11 V3.6.8  Ping to api.safecast.org
2016-03-13 V3.7.1  Redone screen flow
2016-03-13 V3.7.2  ping to Google.com/gw02/gw02 setup
2016-03-14 V3.7.3  setup timing for 3G refresh
2016-03-14 V3.7.4  ping http://safecast-production.s3.amazonaws.com
2016-03-14 V3.7.5  moved countdown and delayed displaying countdown
2016-03-16 V3.7.6  added fails, restarts and create file numbers to EEprom. Added restarts and fails to second line in SDCard
2016-03-17 V3.7.7  file creation counts (logs in stats) added.
2016-03-27 V3.7.8  Display API/DEV toggle implemented , logging new lot to sdcard with stats
2016-03-28 V3.7.9  Fixed after EPROM erase not counting error
2016-04-02 V3.8.0  Sliding window cpm calculation
2016-04-02 V3.8.1  Reading sdcard remove "\r" (windows)
2016-04-19 V3.8.2  push down key delay for menu
2016-04-21 V3.8.3  start counting after all screen of startup are done
2016-04-27 V3.8.4  5 minutes count test
2016-04-28 V3.8.5  fix for Reading sdcard remove "\r\n" (windows)
2016-04-29 V3.8.6  added phone number setup from sdcard for 3G, changed display data to 1 minute, changed NX to 12 and delay to 5000 for 5 seconds measuring, KCPM 2 charater after decimal point
2016-04-30 V3.8.7  fixed new line on new log on sdcard
2016-05-05 V3.8.8  5 minutes display
2016-05-15 V3.8.9  pool.ntp.org as time server dns based
2016-05-15 V3.9.0  Xbee BLEbee setup
2016-05-15 V3.9.1  Menu fixes.
2016-06-09 V3.9.2  Boot delay 3 seconds
2016-06-16 V3.9.3  Changed to 5 minutes count
2016-06-17 V3.9.4  Added Ethernet.maintain() to renew lease before restart
2016-07-04 V3.9.5  reset Wiz820IO modified at startup
2016-07-08 V3.9.6  move week hourly reset in main loop and 3g gim restart first shutdown 3gim module.
2016-07-16 V3.9.7  reset counter just before main loop to avoid wrong first count
2016-07-21 V3.9.8  random minute restart weekly restart
2016-07-27 V3.9.9  fix for DS18S20 to report correctly
2016-07-27 V4.0.0  adjusted display for Ethernet and 3G to display count down in 4 digits and get even spaces for the voltage and temperature.
2016-07-29 V4.0.1  3GIM and Wiz820IO modules reset at startup
2016-07-31 V4.0.2  setup weekly restarts
2016-08-01 V4.0.3  improved weekly restart based on rst value on sdcard
2016-08-05 V4.0.4  daily RTC update
2016-08-10 V4.0.5  moved 3Gpower down/up more sooner in startup. to allow 3GIM module to settle down before accessing it
2016-08-30 V4.0.6  fixed bug with pin assignment of Ethernet
2016-09-09 V4.0.7  fixed retries connect Ethernet
2016-09-09 V4.0.8  added delay between retries Ethernet connect
2016-09-14 V4.0.9  fixed in time sync provider
2016-09-17 V4.1.0  fixed weekly restarts (was not correctly working)
2016-09-17 V4.1.1  fixed Openlog startup detection (was broken in 4.0.9)
2016-09-19 V4.1.2  fixed compiler warnings
2016-09-20 V4.1.3  NTP server timeout retries at 5 minutes.
2016-09-21 V4.1.4  fixes freezes on time update
2016-09-22 V4.1.5  Cleaned up formatting
2016-09-23 V4.1.6  setup NTP check for 15 seconds retries and 300 seconds timeout
2016-09-23 V4.1.7  setup to renew a lease for DHCP every 5 minutes for networks that have short DHCP lease setup
2016-09-24 V4.1.8  conditional setup of the Ethernet.maintain() function to restart the Ethernet connection id a new lease or a rebind can not obtained.
2016-10-16 V4.1.9  Added confirmation for measurement ID from API to be sure data is accepted in the Database.
2016-10-28 V4.2.0  Status data to API.
2016-10-28 V4.2.1  Status data to API with fix for Ethernet.
2016-10-28 V4.2.2  Ethernet reply message of measurement_id of for API setup for displaying on terminal 
2016-10-31 V4.2.3  3G cleanup code 
2016-11-11 V4.2.4  3G send error message corrected.
2017-02-14 V4.2.5  SD card can now be edited in Windows (ray fixed the import code)
2018-06-02 V4.2.7 .SD card can now be edited in Windows (ray new fix)


contact rob@yr-design.biz
 */

/**************************************************************************/
// Init
/**************************************************************************/


#define ENABLE_DEBUG

#include <SPI.h>         // needed for Arduino versions later than 0018
#include <Ethernet.h>
#include <EthernetUdp.h>
#include <EEPROM.h>
#include <limits.h>
#include <SoftwareSerial.h>
#include <Time.h>
#include <TimeLib.h>
#include <TimeAlarms.h>
#include <i2c_t3.h>
#include <LiquidCrystal_I2C.h>
#include <OneWire.h>
#include <limits.h>
#include "a3gim.h"
#include "PointcastSetup.h"
#include "PointcastDebug.h"

//setup LCD I2C
#define I2C_ADDR    0x27  // Define I2C Address where the PCF8574 is for LCD2004 form http://www.sainsmart.com  the PCF8574A is 0x3f
#define BACKLIGHT_PIN     3
#define En_pin  2
#define Rw_pin  1
#define Rs_pin  0
#define D4_pin  4
#define D5_pin  5
#define D6_pin  6
#define D7_pin  7

int n = 1;
LiquidCrystal_I2C lcd(I2C_ADDR, En_pin, Rw_pin, Rs_pin, D4_pin, D5_pin, D6_pin, D7_pin);
int green_ledPin = 31;
int red_ledPin = 26;

// 3G signal strengh
int rssi = -125;

//setup Power detection
#define VOLTAGE_PIN A13
#define VOLTAGE_R1 100000
#define VOLTAGE_R2 10000

//sliding windows counting variables
#define NX 60
#define TIME_INTERVAL 5000
#define IS_READY (interruptCounterAvailable())

//setup Onewire for temp sensor
OneWire  ds(32);  // on pin 10 of extra header(a 4.7K resistor is necessary)

//main menu variable
boolean finished_startup = false;
boolean network_startup = false;
boolean sdcard_startup = false;
boolean pingConnect = false;


#define LINE_SZ 128
// SENT_SZ is used for sending data for 3G
#define SENT_SZ 512
//OLINE_SZ is used for OpenLog buffers
#define OLINE_SZ 512
//GATEWAY_sz is array for gateways
#define GATEWAY_SZ 2


static char obuf[OLINE_SZ];
static char buf[LINE_SZ];
static char buf2[LINE_SZ];
static char strbuffer[32];
static char strbuffer1[32];
char body[512];
char body2[512];
char body3[512];
char STATS[255];
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
void loop() {

  // Main Loop
  finished_startup = true;

  // check for weekly alarm
  Alarm.delay(0);


  //display timer setup

  int leftMillis = (updateIntervalInMillis - elapsedTime(lastConnectionTime));
  int left_secs = leftMillis / 1000; //convert milliseconds to seconds
  int left_mins = left_secs / 60; //convert seconds to minutes
  left_secs = left_secs - (left_mins * 60); //subtract the converted seconds to minutes in order to display 59 secs max

  //display current countdown time
  if (displayTimeOn) {
    lcd.setCursor(15, 3);
    printDigitsSingle(left_mins);
    lcd.print(":");
    printDigits(left_secs);
  }



  unsigned long cpb1 = 0, cpb2 = 0;

  if (elapsedTime(lastConnectionTime) < updateIntervalInMillis)
  {

    if (joyCntB) {
#ifdef ENABLE_DEBUG
      Serial.println ("Up");
#endif
      joyCntB = !joyCntB; joyCntA = false; joyCntD = false; joyCntE = false; lcd.clear(); display_interval = 1000; Menu_datalogger(); return;
    }

    if (joyCntA) {
#ifdef ENABLE_DEBUG
      Serial.println ("Down");
#endif
      joyCntA = !joyCntA; joyCntD = false; joyCntB = false; joyCntE = false; lcd.clear(); display_interval = 1000; Menu_stat(); return;
    }
    if (joyCntE) {

#ifdef ENABLE_DEBUG
      Serial.println ("Enter");
#endif
      joyCntE = !joyCntE; joyCntD = false; joyCntB = false; joyCntA = false; digitalWrite(26, LOW); return;
    }
    if (joyCntD) {

#ifdef ENABLE_DEBUG
      Serial.println ("Right");
#endif
      joyCntD = !joyCntD; joyCntA = false; joyCntB = false; lcd.clear(); joyCntE = false; display_interval = 1000; Menu_term(); return;
    }


    //sliding window setup

    if IS_READY {

    cpb1 = interruptCounterCount();
      cpb2 = interruptCounterCount2();

      interruptCounterReset();

      // insert count in sliding window and compute CPM
      shift_reg[reg_index] = cpb1;     // put the count in the correct bin
      reg_index = (reg_index + 1) % NX; // increment register index
      cpm1 = cpm_gen1();               // compute sum over all bins

      // insert count in sliding window and compute CPM2
      shift_reg2[reg_index2] = cpb2;    // put the count in the correct bin
      reg_index2 = (reg_index2 + 1) % NX; // increment register index
      cpm2 = cpm_gen2();  // compute sum over all bins
    }

    Alarm.delay(0);
    return;

  }

#ifdef ENABLE_DEBUG
  Serial.print("FreeRam = ");
  Serial.println(FreeRam());
#endif

  SendDataToServer(cpm1, cpm2);
}


///**************************************************************************/
// Menus for stat etc..
//**************************************************************************/

void Menu_stat() {
  displayTimeOn = false;
  lcd.clear();
  previousMillis = millis() ;
  while ((unsigned long)(millis() - (unsigned long)previousMillis) <= (unsigned long)display_interval) {

    if (joyCntB) {
#ifdef ENABLE_DEBUG
      Serial.println ("Up");
#endif
      joyCntB = !joyCntB; joyCntA = false; lcd.clear(); display_interval = 3000; displayTimeOn = true; Menu_counting(); return;
    }

    if (joyCntA) {
#ifdef ENABLE_DEBUG
      Serial.println ("Down");
#endif
      joyCntA = !joyCntA; joyCntB = false; display_interval = 500; Menu_stat2(); return;
    }

    lcd.setCursor(0, 0);
    lcd.print("STATS");
    lcd.setCursor(0, 1);
    lcd.print("S1peak=");
    lcd.print(config.S1peak);
    lcd.setCursor(0, 2);
    lcd.print("S2peak=");
    lcd.print(config.S2peak);
    lcd.setCursor(0, 3);
    lcd.print("FreeRam=");
    lcd.print(FreeRam());

  }
}

//**************************************************************************/
// Menus for stat2
//**************************************************************************/

void Menu_stat2() {

  displayTimeOn = false;
  // check timeup
  currentmillis = millis(); // get the  current milliseconds from arduino
#ifdef ENABLE_DEBUG
  Serial.print("Total milliseconds running: ");
#endif
  display_secs = currentmillis / 1000; //convect milliseconds to seconds
  display_mins = display_secs / 60; //convert seconds to minutes
  display_hours = display_mins / 60; //convert minutes to hours
  display_days = display_hours / 24; //convert hours to days
  display_secs = display_secs - (display_mins * 60); //subtract the converted seconds to minutes in order to display 59 secs max
  display_mins = display_mins - (display_hours * 60); //subtract the converted minutes to hours in order to display 59 minutes max
  display_hours = display_hours - (display_days * 24); //sub
#ifdef ENABLE_DEBUG
  Serial.printf("%d days, %d hours, %d minutes \n", display_days, display_hours, display_mins);
#endif

  lcd.clear();
  previousMillis = millis() ;
  while ((unsigned long)(millis() - (unsigned long)previousMillis) <= (unsigned long)display_interval) {

    if (joyCntB) {
#ifdef ENABLE_DEBUG
      Serial.println ("Up");
#endif
      joyCntB = !joyCntB; joyCntA = false; lcd.clear(); display_interval = 3000; Menu_stat(); return;
    }

    if (joyCntA) {
#ifdef ENABLE_DEBUG
      Serial.println ("Down");
#endif
      joyCntA = !joyCntA; joyCntB = false; lcd.clear(); display_interval = 3000; displayTimeOn = true; Menu_counting(); return;
    }

    lcd.setCursor(0, 0);
    lcd.print("up=");
    lcd.print(display_days);
    lcd.print("d ");
    lcd.print(display_hours);
    lcd.print("h ");
    lcd.print(display_mins);
    lcd.print("m ");
    lcd.setCursor(0, 1);
    lcd.print("#logs=");
    lcd.print(dose.logs);
    lcd.setCursor(0, 2);
    lcd.print("#fail=");
    lcd.print(dose.fails);
    lcd.setCursor(0, 3);
    lcd.print("#restarts=");
    lcd.print(dose.restarts);
  }
  return;
}

//**************************************************************************/
// Menus for terminal
//**************************************************************************/

void Menu_term() {
  displayTimeOn = false;
  lcd.clear();
  previousMillis = millis() ;
  while ((unsigned long)(millis() - (unsigned long)previousMillis) <= (unsigned long)display_interval) {
    if (joyCntB) {
#ifdef ENABLE_DEBUG
      Serial.println ("Up");
#endif
      joyCntB = !joyCntB; joyCntA = false; lcd.clear(); display_interval = 3000; displayTimeOn = true; Menu_counting(); return;
    }
    if (joyCntA) {
#ifdef ENABLE_DEBUG
      Serial.println ("Up");
#endif
      joyCntA = !joyCntA; joyCntB = false; display_interval = 500; displayTimeOn = true; Menu_counting(); return;
    }

#if ENABLE_3G
    String res_string(res);
    int startChar = res_string.indexOf("\"id\":");
    res_string.remove(0, startChar + 5);
    int endComma = res_string.indexOf(",");

    String res2_string(res2);
    int startChar2 = res2_string.indexOf("\"id\":");
    res2_string.remove(0, startChar2 + 5);
    int endComma2 = res2_string.indexOf(",");

    String res4_string(res4);
    int startChar4 = res4_string.indexOf("\"id\":");
    res4_string.remove(0, startChar4 + 5);
    int endComma4 = res4_string.indexOf(",");
#endif

#if ENABLE_ETHERNET


#endif

    lcd.setCursor(0, 0);
    lcd.print("Terminal: API ID");
    lcd.setCursor(0, 1);
    lcd.print("S1=");
#if ENABLE_3G
    if (startChar != -1) {
      lcd.print(res_string.substring(0, endComma));
    }
#endif

#if ENABLE_ETHERNET
    lcd.print(GetmeasurementReplyReturn);
#endif

    lcd.setCursor(0, 2);
    lcd.print("S2=");
#if ENABLE_3G
    if (startChar2 != -1) {
      lcd.print(res2_string.substring(0, endComma2));
    }
#endif

#if ENABLE_ETHERNET
    lcd.print(GetmeasurementReplyReturn1);
#endif
    lcd.setCursor(0, 4);
    lcd.print("TMP=");
#if ENABLE_3G
    if (startChar4 != -1) {
      lcd.print(res4_string.substring(0, endComma4));
    }
#endif

#if ENABLE_ETHERNET
    lcd.print(GetmeasurementReplyReturn2);
#endif

  }
  Menu_counting();
}


/**************************************************************************/
// calculate elapsed time, taking into account rollovers
/**************************************************************************/
unsigned long elapsedTime(unsigned long startTime)
{
  unsigned long stopTime = millis();

  if (startTime >= stopTime)
  {
    return startTime - stopTime;
  }
  else
  {
    return (ULONG_MAX - (startTime - stopTime));
  }
}



/**************************************************************************/
// OpenLog code
/**************************************************************************/

/* wait for openlog prompt */
bool waitOpenLog(bool commandMode) {
  int safeguard = 0;
  bool result = false;

  while (safeguard < OPENLOG_RETRY) {
    safeguard++;
    if (OpenLog.available())
      if (OpenLog.read() == (commandMode ? '>' : '<')) break;
    delay(10);
  }

  if (safeguard >= OPENLOG_RETRY) {
  } else {
    result = true;
  }

  return result;
}
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

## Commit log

2015-02-28 initial project version
    [CONFIG.TXT, Teensy 3Gshield lower board V0.97.brd, Teensy 3Gshield lower board V0.97.sch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]
2015-03-09 Added libraries and new boards
2015-03-09 Added more files
    [nGeigie V2.0 lower board V1.00.brd, nGeigie V2.0 lower board V1.00.sch, nGeigie_upper_boardV1.00.brd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]
2015-03-09 Update I2C library and added Hex file
2015-03-09 Added Gerber files
2015-03-09 Cleaned up code, added final boards.
2015-04-05 Added LED check on startup..
2015-04-06 LED delay setup
2015-04-09 Switch between DEV and API sending the data...
2015-04-13 added switch for switching from Ethernet and other options to switch in the coding without recompile.
2015-04-14 Switched back to two compile versions(3G and Ethernet) and added setup variables
2015-04-21 V2.6.8 added device ID, startup screen change, header for file format changed to NGRDD
2015-04-23 Sensor header added as second line on SDcard
2015-04-27 Added latest boards
    [Teensy 3Gshield lower board V0.97.brd, Teensy 3Gshield lower board V0.97.sch, Teensy 3Gshield upper board V0.97.brd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]
2015-04-27 And the boards
    [Pointcast_lower_board_V1.02.brd, Pointcast_lower_board_V1.02.sch, Pointcast_upper_board_V1.02.brd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]
2015-04-30 Added temperature setup for DS18B20 (disabled at the moment) setup screens
2015-05-14 BOM updated
2015-05-16 Extra files added
    [Pointcast V1.0 _1.0.2_resistors.xlsx, Pointcastv1.0_1.0.2_BOM lower board.xlsx, Pointcastv1.0_1.0.2_BOM upper board.xlsx]
2015-06-07 Temperature setup, APIKEY display, battery/power updated
2015-06-09 Temperature fix and some display changes.
2015-06-17 Fixes for sdcard temp and battery, file naming, etc
2015-06-20 V2.9.8 Switch between API and DEV by sdcard setting (dev=1 for sending data to dev.safecast.org)
2015-08-18 Changed voltage display to compansate for voltage drop over D103
2015-08-20 Switched Teensy to intrenal reference mode 1.2V
2015-08-25 Added Carrier display for 3G and change voltage display with no diode compensation
2015-09-02 Add libs
    [CONFIG.TXT, Pointcast V1.0 _1.0.2_resistors.xlsx, Pointcast_lower_board_V1.02.brd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]
2015-09-02 And the rest of the files
    [CONFIG.TXT, Pointcast V1.0 _1.0.2_resistors.xlsx, Pointcast_lower_board_V1.02.brd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]
2015-09-19 V3.2.8 Added single sensor not faling on test
2015-09-28 Weekly reset setup
    [Pointcast_lower_board_V1.03.brd, Pointcast_lower_board_V1.03.sch, Pointcast_upper_board_V1.03.brd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]
2015-11-17 V3.3.6 added reset failure LED by enter (push down) joyswitch
2016-01-24 Added extra code for different temperature sensors.
2016-01-26 Changed way to send data for 3G ..powerup-send-powerdown...
2016-03-27 V3.7.8 added temperature on main screen, dev and api switch on display, logging header with logs, retarts and fails
    [Pointcast_lower_board_V1.02.brd, Pointcast_lower_board_V1.02.sch, Pointcast_lower_board_V1.03.brd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]
2016-05-05 Added Kicad files for V1.03 board
    [Pointcast_lower_board_V1.03.kicad_pcb, Pointcast_upper_board_V1.03.kicad_pcb, noname.kicad_pcb]
2016-07-16 V3.9.7 Added interruptCounterReset() just before count starts
2016-07-27 V3.9.9 fixed for DS18S20 sensor.
2016-07-27 V4.0.0 adjusted display for ethernet and 3G to display count down in 4 digits and get even spaces for the voltage and temperature.
2016-07-29 V4.0.2 Misc 3G and Ethernet connection changes
    [CONFIG.TXT]
2016-08-10 V4.0.5 moved 3GIM powerdown/up closer to startup to give 3GIM module more time settle down before startup
2016-08-28 Added holes for glands placement for Ethernet
    [bottom plate holes.skp, main body holes.skp]
2016-08-28 Updated holes pictures
    [bottom plate holes.skp, main body holes.skp]
2016-08-29 V4.0.6 fixes Ethernet S1 LED problem.
2016-09-20 V4.1.4 Fixed temp sensor
2016-11-08 Added correct drill template box and sdcard configs zipped
    [Pointcast_upper_board_V1.03.brd, Pointcast_upper_board_V1.03.sch]
2016-11-21 Added teensy.exe for windows teensy flashing
2016-11-21 Change the Teensy.exe for zipped version
2016-12-10 Updated hole placement for case.

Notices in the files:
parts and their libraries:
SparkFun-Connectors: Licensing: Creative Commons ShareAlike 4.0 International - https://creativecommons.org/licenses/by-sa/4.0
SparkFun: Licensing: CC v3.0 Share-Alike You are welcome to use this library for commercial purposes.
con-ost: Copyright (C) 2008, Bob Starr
